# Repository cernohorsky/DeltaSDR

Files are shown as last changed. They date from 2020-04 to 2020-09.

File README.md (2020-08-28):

# DeltaSDR
HF Software Defined Radio Transceiver that includes ADC and DAC circuits. No soundcard is needed. Board communicates only trough one USB cable. Very good software support trough Hamlib. Ideal for digital modes such a FT8 on Raspberry Pi.

- 96kHz digital I/Q interface.
- more then 80dB dynamic range.
- DG8SAQ/PE0FKO/SoftRock control interface.
- Open Source firmware (https://github.com/AE9RB/peaberry)
- SWD/JTAG port.

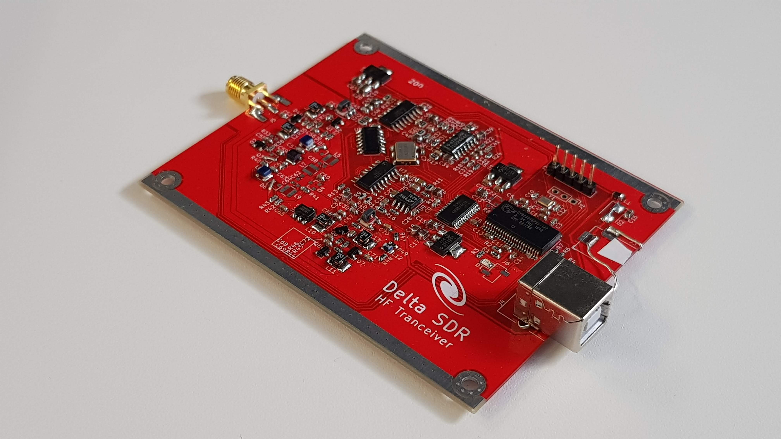
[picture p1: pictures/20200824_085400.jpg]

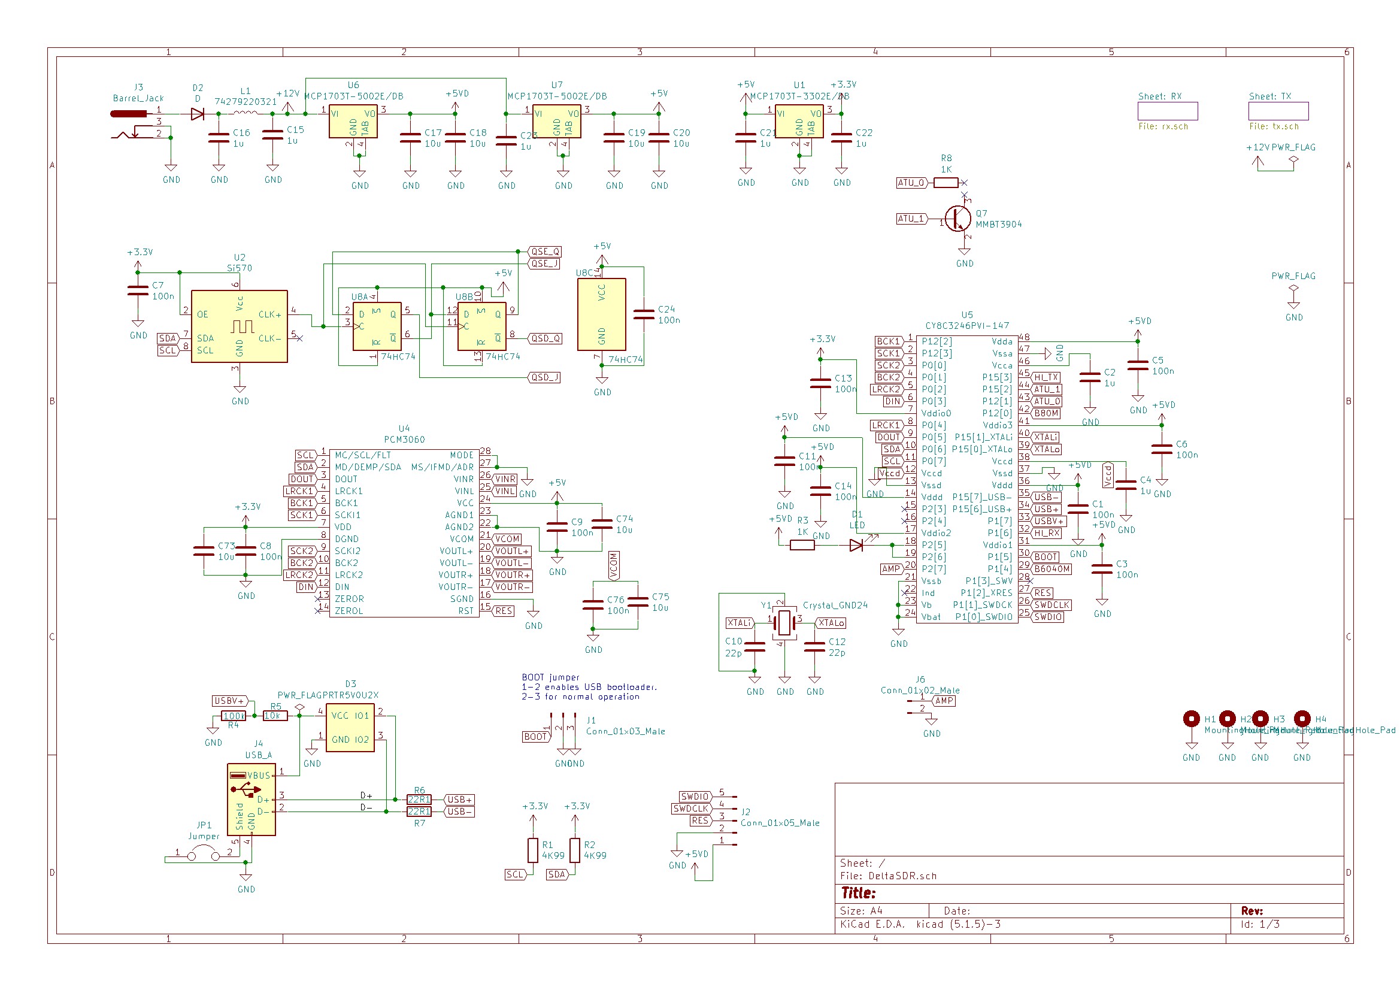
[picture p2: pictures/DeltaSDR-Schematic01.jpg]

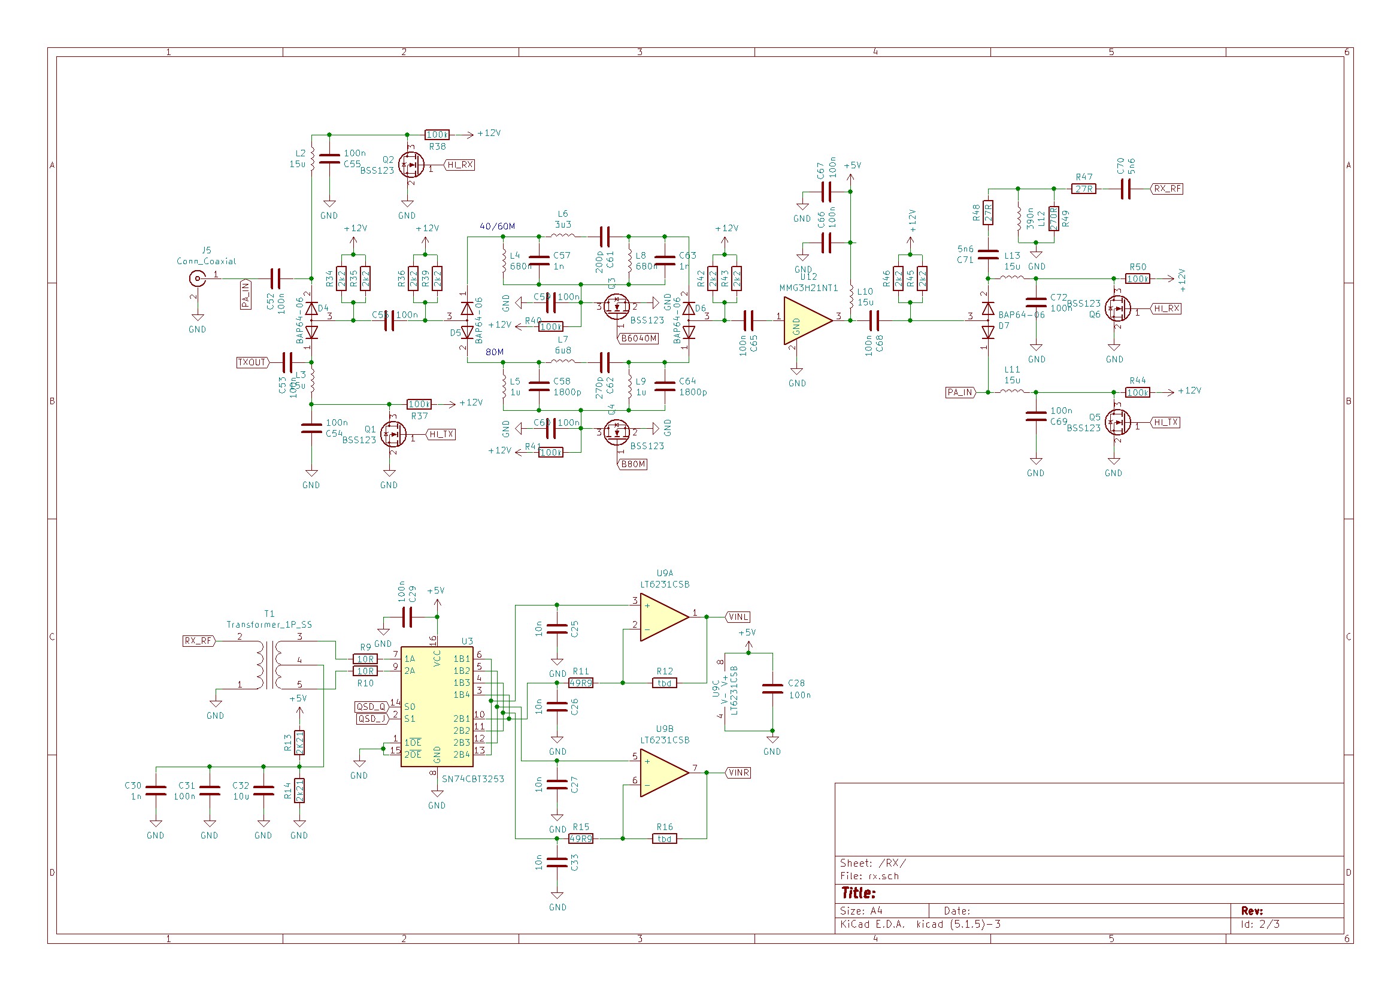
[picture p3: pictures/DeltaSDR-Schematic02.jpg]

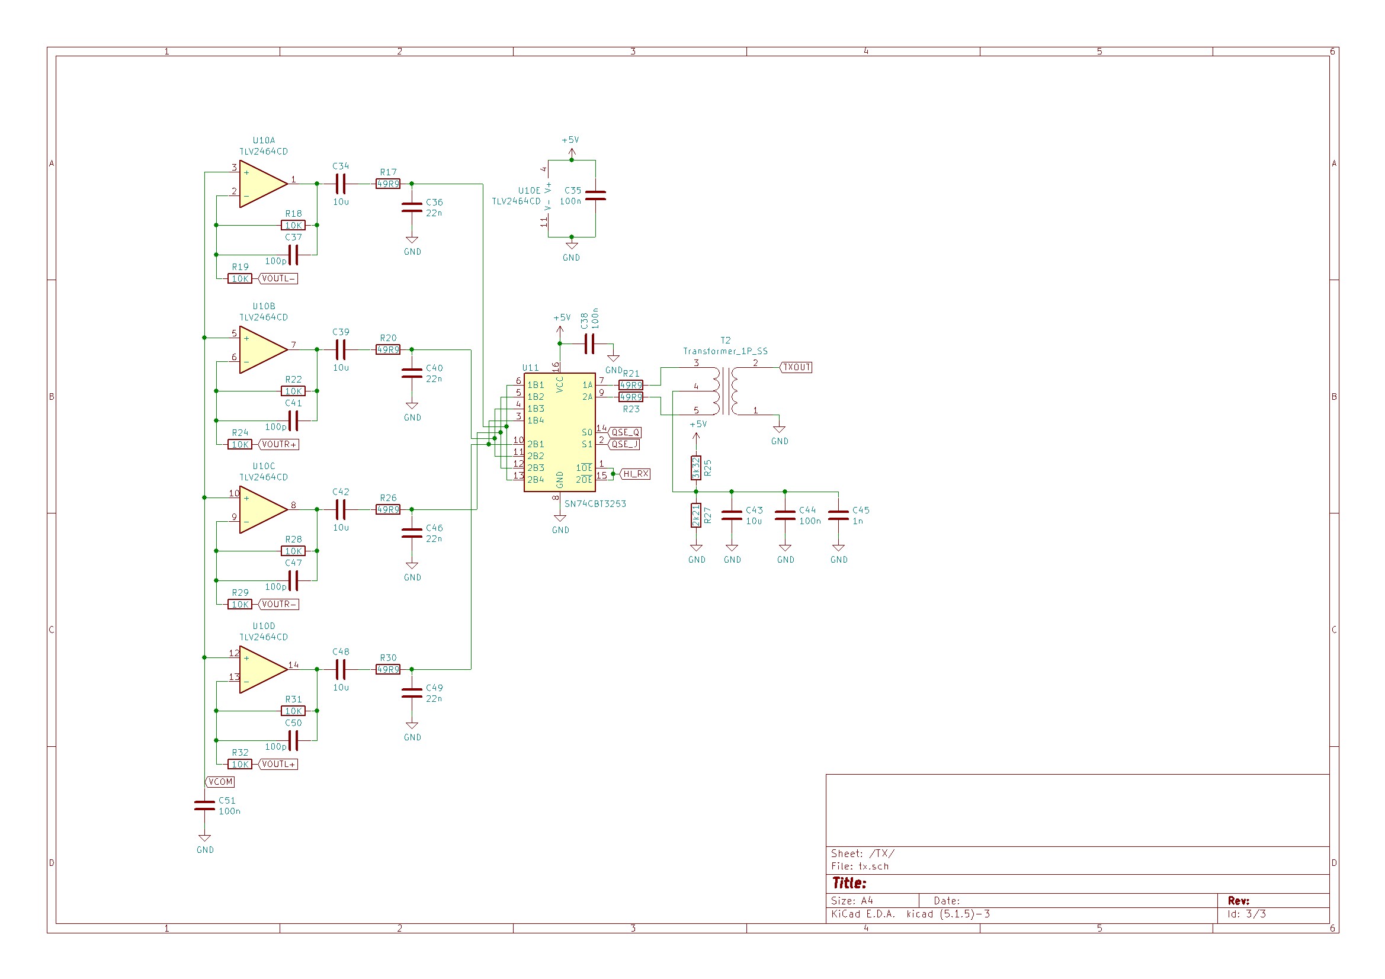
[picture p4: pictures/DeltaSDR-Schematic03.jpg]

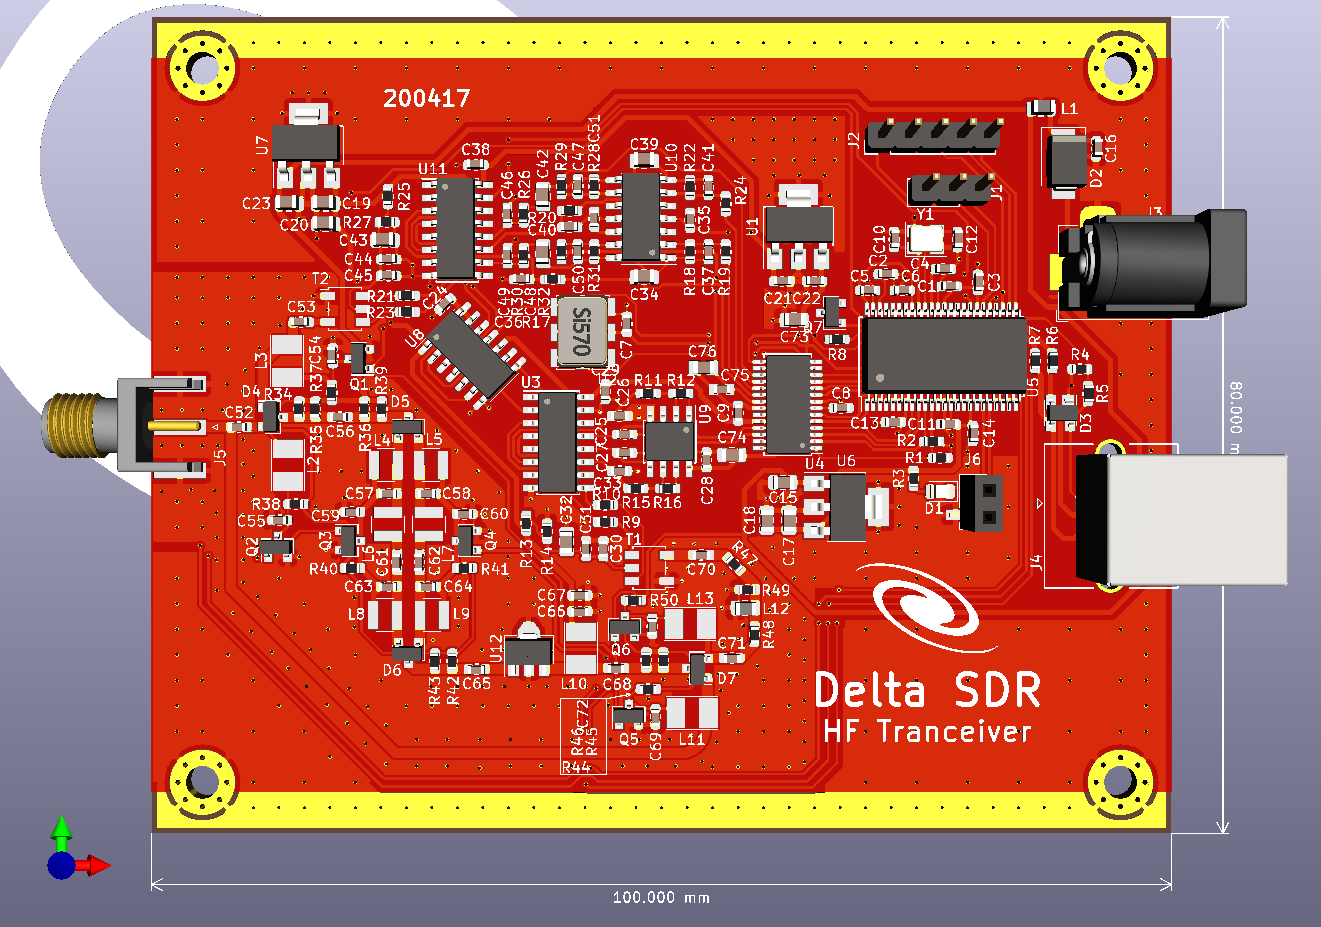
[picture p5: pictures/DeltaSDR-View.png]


ToDo:
- Change SMA and USB footprints
- Add PA
- Implement band switching

Based on: AE9RB Peaberry SDR and RS-HFIQ Transceiver

#sdr, #hf, #ham, #radio, #ft8, #wsjt-x, #shortwave, #usb

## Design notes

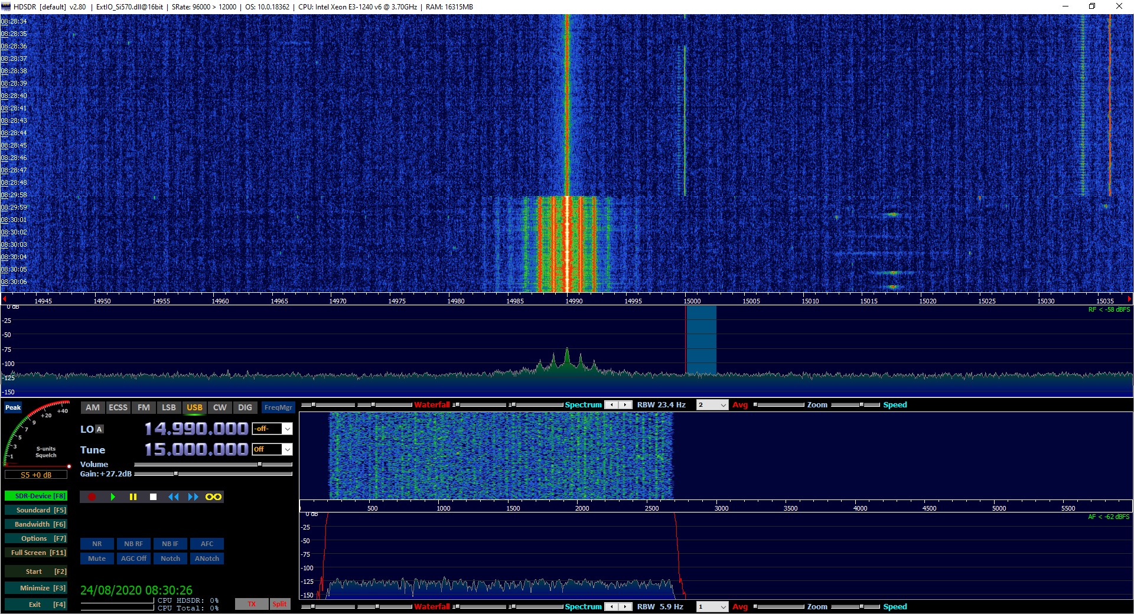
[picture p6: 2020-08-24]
pictures/20200824-DeltaSDR-LinearVsUSB.jpg

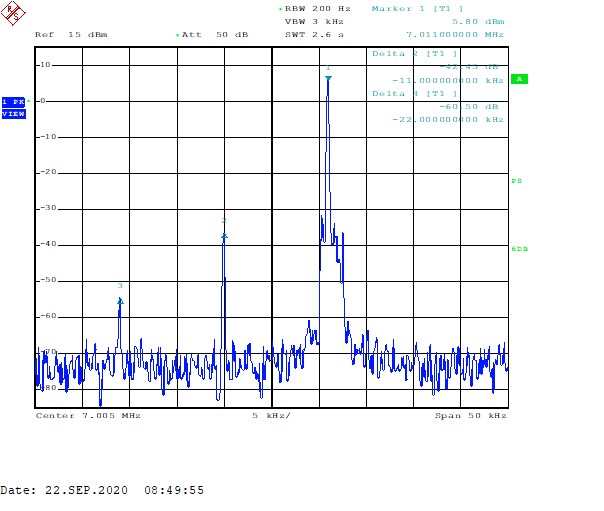
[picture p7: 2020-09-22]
pictures/20200922-DELTA-SDR-TX.jpg

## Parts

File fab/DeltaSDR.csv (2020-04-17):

Id | Designator | Package | Quantity | Designation | Supplier and ref
1 | C74,C73,C39,C32,C43,C48,C42,C34,C23,C20,C19,C18,C17,C15 | C_0805_2012Metric | 14 | 10u
2 | C24,C72,C69,C68,C67,C66,C65,C60,C59,C56,C55,C54,C53,C52,C51,C50,C47,C44,C41,C38,C37,C35,C31,C29,C28,C14,C13,C11,C9,C8,C7,C6,C5,C3,C1 | C_0603_1608Metric | 35 | 100n
3 | U8 | SOIC-14_3.9x8.7mm_P1.27mm | 1 | 74HC74
4 | J6 | PinSocket_1x02_P2.54mm_Vertical_SMD_Pin1Right | 1 | Conn_01x02_Male
5 | G*** | DeltaSymbol | 1 | LOGO
6 | C16,C22,C21,C4,C2 | C_0603_1608Metric | 5 | 1u
7 | L1 | L_0805_2012Metric | 1 | 74279220321
8 | D2 | D_SMB | 1 | D
9 | G*** | RiskeLogo | 1 | RiskeLogo
10 | U1 | SOT-223 | 1 | TC1262-33
11 | U7,U6 | SOT-223 | 2 | TC1262-5
12 | H4,H3,H2,H1 | MountingHole_3.2mm_M3_Pad_Via | 4 | MountingHole_Pad
13 | JP1 | SolderJumper-2_P1.3mm_Open_RoundedPad1.0x1.5mm | 1 | Jumper
14 | R5 | R_0603_1608Metric | 1 | 10k
15 | C70,C71 | C_0603_1608Metric | 2 | 5n6
16 | R13 | R_0603_1608Metric | 1 | 2K21
17 | R14,R27 | R_0603_1608Metric | 2 | 2k21
18 | J3 | BarrelJack_Horizontal | 1 | Barrel_Jack
19 | T2,T1 | Transformer_MACOM_SM-22 | 2 | Transformer_1P_SS
20 | U11,U3 | SOIC-16_4.55x10.3mm_P1.27mm | 2 | SN74CBT3253
21 | Y1 | Crystal_SMD_3225-4Pin_3.2x2.5mm | 1 | Crystal_GND24
22 | U12 | SOT-89-3 | 1 | MMG3H21NT1
23 | U10 | SOIC-14_3.9x8.7mm_P1.27mm | 1 | TLV2464CD
24 | U9 | SO-8_3.9x4.9mm_P1.27mm | 1 | LT6231CSB
25 | U5 | SSOP-48_7.5x15.9mm_P0.635mm | 1 | CY8C3246PVI-147
26 | U4 | TSSOP-28_4.4x9.7mm_P0.65mm | 1 | PCM3060
27 | U2 | Oscillator_SMD_SI570_SI571_Standard | 1 | Si570
28 | R50,R44,R41,R40,R38,R37,R4 | R_0603_1608Metric | 7 | 100k
29 | R49 | R_0603_1608Metric | 1 | 270R
30 | R48,R47 | R_0603_1608Metric | 2 | 27R
31 | R46,R45,R43,R42,R39,R36,R35,R34,R33 | R_0603_1608Metric | 9 | 2k2
32 | R32,R31,R29,R28,R24,R22,R19,R18 | R_0603_1608Metric | 8 | 10K
33 | R30,R26,R23,R21,R20,R17 | R_0603_1608Metric | 6 | 49k9
34 | R25 | R_0603_1608Metric | 1 | 3k32
35 | R16,R12 | R_0603_1608Metric | 2 | tbd
36 | R15,R11 | R_0603_1608Metric | 2 | 49R9
37 | R10,R9 | R_0603_1608Metric | 2 | 10R
38 | R7,R6 | R_0603_1608Metric | 2 | 22R1
39 | R3,R8 | R_0603_1608Metric | 2 | 1K
40 | R2,R1 | R_0603_1608Metric | 2 | 4K99
41 | Q6,Q5,Q4,Q3,Q2,Q1 | SOT-23 | 6 | BSS123
42 | L13,L11,L10,L3,L2 | L_Taiyo-Yuden_NR-30xx_HandSoldering | 5 | 15u
43 | L12 | L_0805_2012Metric | 1 | 390n
44 | L9,L5 | L_Abracon_ASPI-3012S | 2 | 1u
45 | L8,L4 | L_Abracon_ASPI-3012S | 2 | 680n
46 | L7 | L_Abracon_ASPI-3012S | 1 | 6u8
47 | L6 | L_Abracon_ASPI-3012S | 1 | 3u3
48 | J5 | SMA_Amphenol_132289_EdgeMount | 1 | Conn_Coaxial
49 | J4 | USB_B_TE_5787834_Vertical | 1 | USB_A
50 | J2 | PinHeader_1x05_P2.54mm_Vertical | 1 | Conn_01x05_Male
51 | J1 | PinHeader_1x03_P2.54mm_Vertical | 1 | Conn_01x03_Male
52 | D7,D6,D5,D4 | SOT-23 | 4 | BAP64-06
53 | D3 | SOT-143 | 1 | PRTR5V0U2X
54 | D1 | LED_0805_2012Metric | 1 | LED
55 | C64,C58 | C_0603_1608Metric | 2 | 1800p
56 | C63,C57,C45,C30 | C_0603_1608Metric | 4 | 1n
57 | C62 | C_0603_1608Metric | 1 | 270p
58 | C61 | C_0603_1608Metric | 1 | 200p
59 | C49,C46,C40,C36 | C_0603_1608Metric | 4 | 22n
60 | C33,C27,C26,C25 | C_0805_2012Metric | 4 | 10n
61 | C12,C10 | C_0603_1608Metric | 2 | 22p
62 | Q7 | SOT-23 | 1 | MMBT3904

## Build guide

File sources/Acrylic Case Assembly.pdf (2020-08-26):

Take some time to study
this first picture. The pieces are laid out how they will fit together. The top piece is not in the photograph.

All pieces will have a
protective film on them. Use your fingernail to lift a
corner and it will peel off easily.

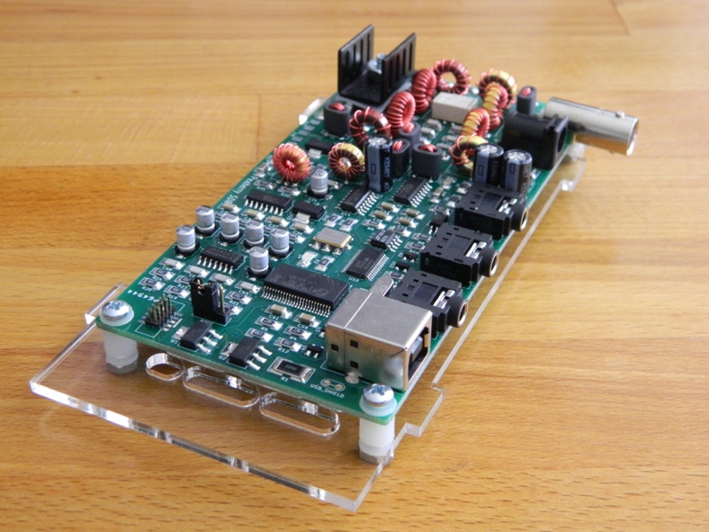
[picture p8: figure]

Begin by attaching the
circuit board to the bottom panel. The 1/2” #4 screws
that came with your radio
aren’t long enough so use
the 5/8” #4 screws that
came with the case. The
case also comes with four
more nylon washers to put
between the nut and the
acrylic.

Do not tighten the nuts yet. Allow the board to float
around for now.

Ensure the cooling vents
are positioned as in the
photograph.

# Acrylic Case for Peaberry SDR Page 1/3

Attach the connector panel next. With this in place you can tighten the nuts holding the circuit board.

Expect some resistance the first time you insert a tab into a slot.

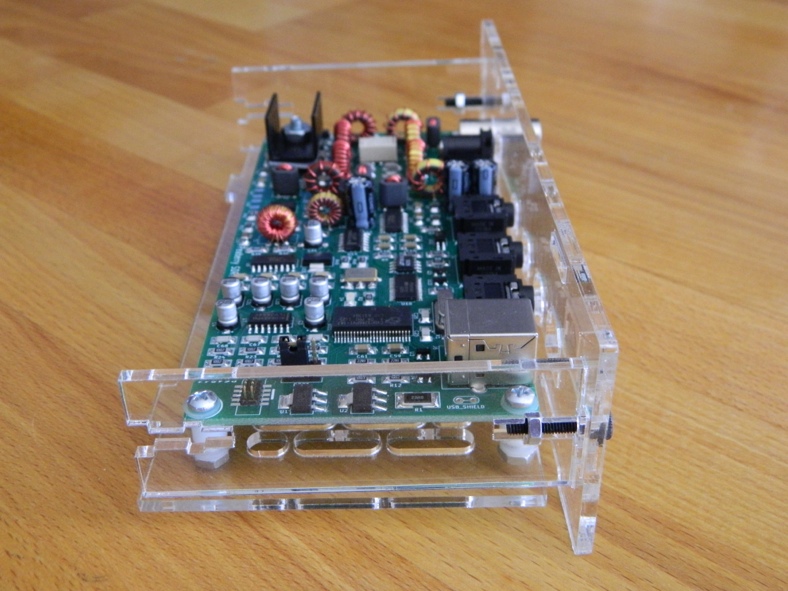
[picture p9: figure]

Install the inner side panels and the M3 hardware. Hold
the nuts in place with your fingers when starting the
screw. Install the screws
only finger-tight for now.

Install the next panel and M3 hardware. Once in
place you will have to
loosen the M3 hardware
and install the remaining
three panels. This
procedure is a little wonky but you’ll get through it with a bit of trial and error.

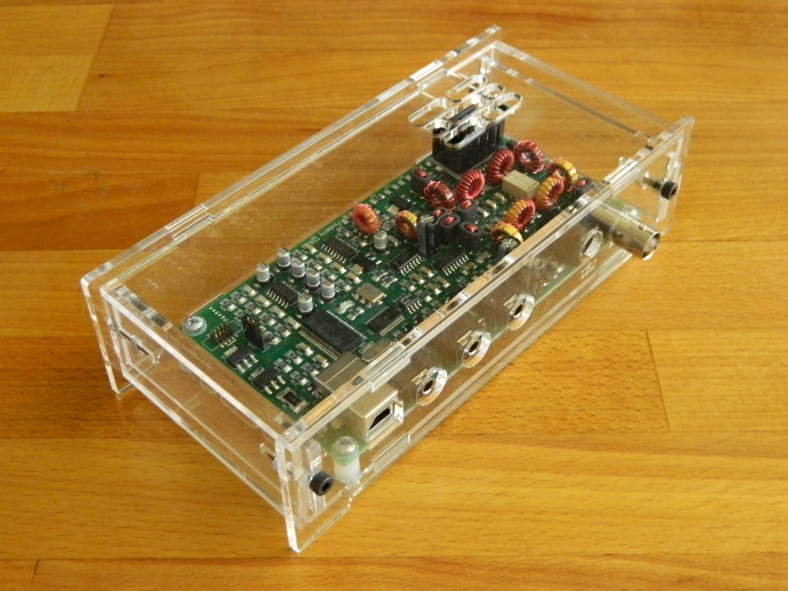
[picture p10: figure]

With all the panels installed you can tighten the M3
hardware with the included wrench. Insert the long end of the wench into the screw caps so you do not overtighten these.

Enjoy your new case. Clean with a damp cloth using
regular soap if needed. Do not use any ammoniabased cleaners.

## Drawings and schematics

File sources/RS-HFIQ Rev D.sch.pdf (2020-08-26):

A

A

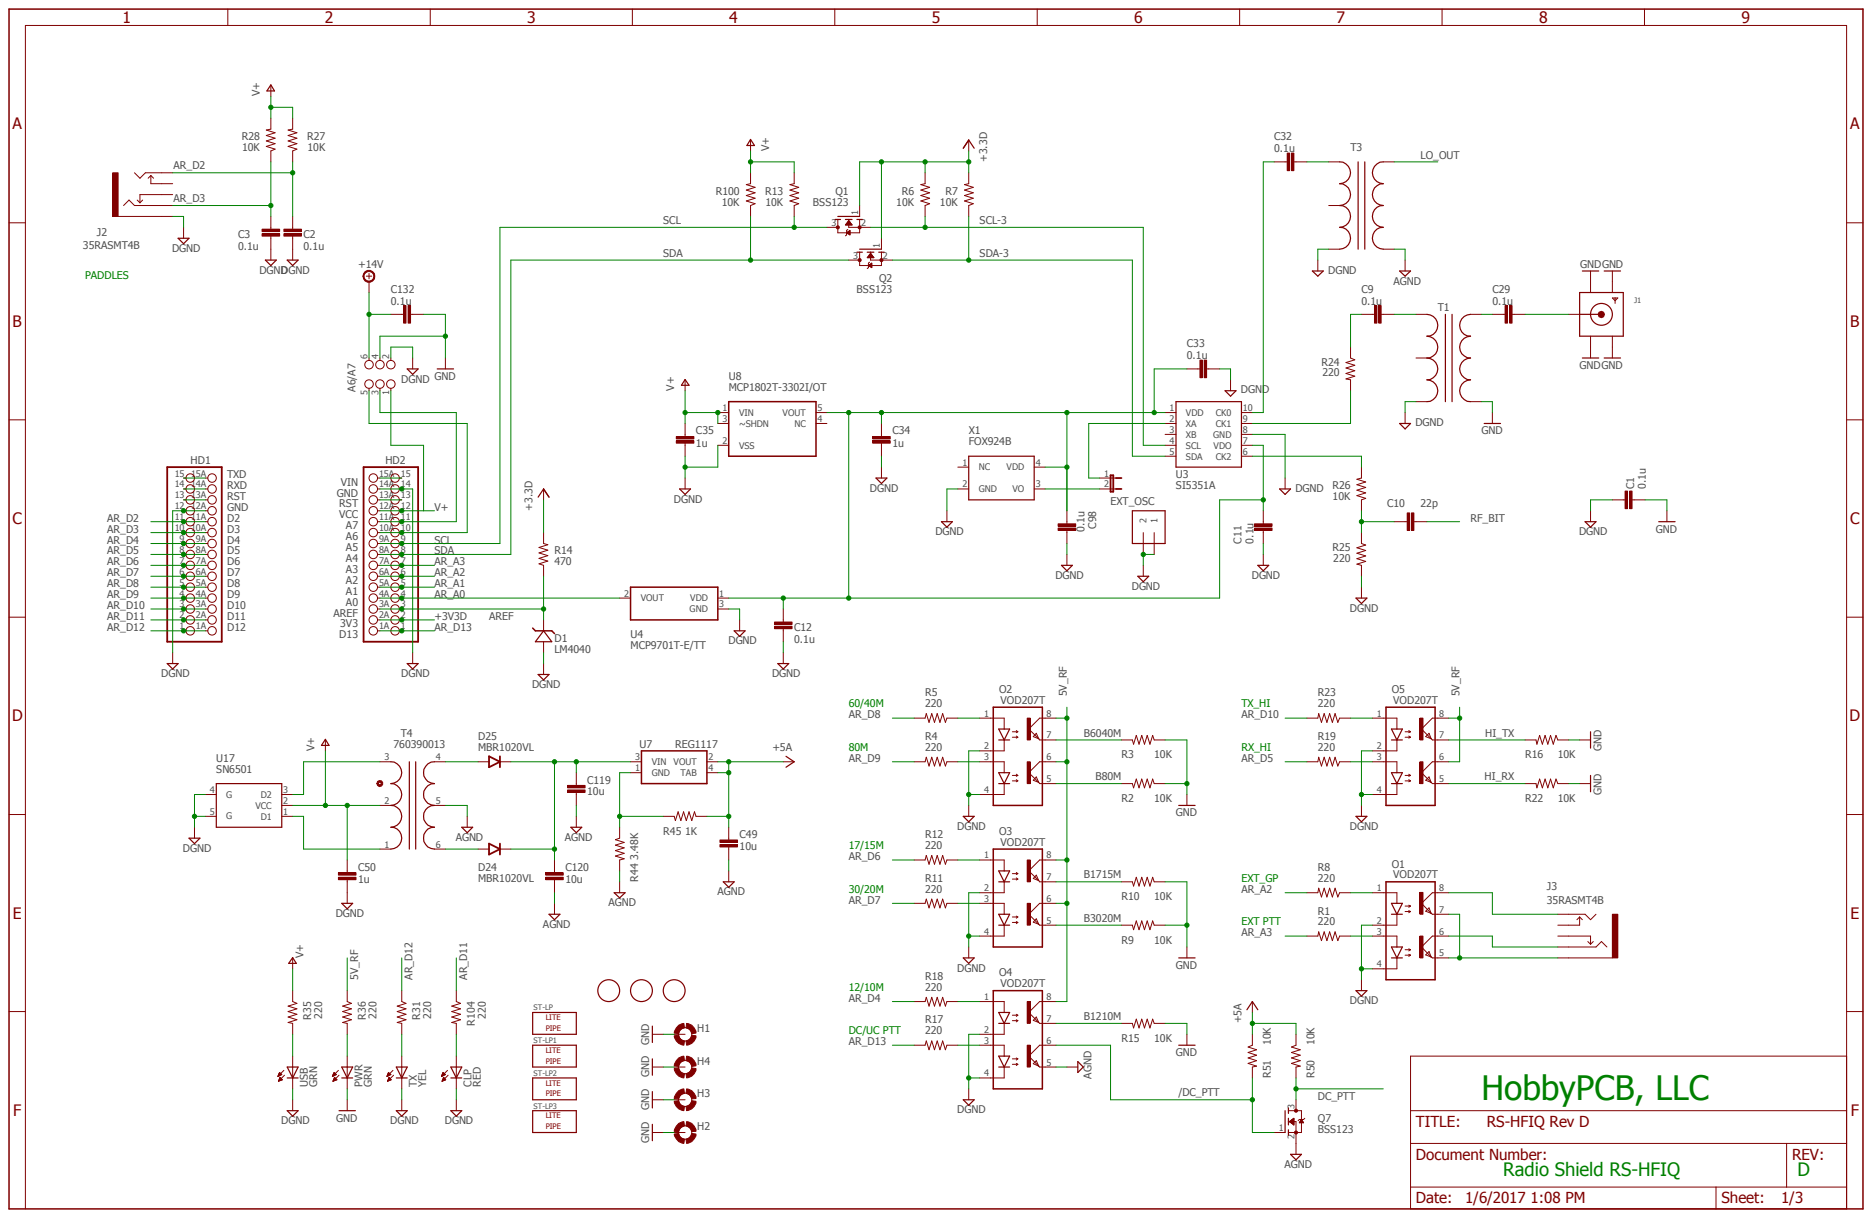
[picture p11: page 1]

GND GND

Document Number: Radio Shield RS-HFIQ | REV: D

Date: 1/6/2017 1:08 PM | Sheet: 1/3

A

A

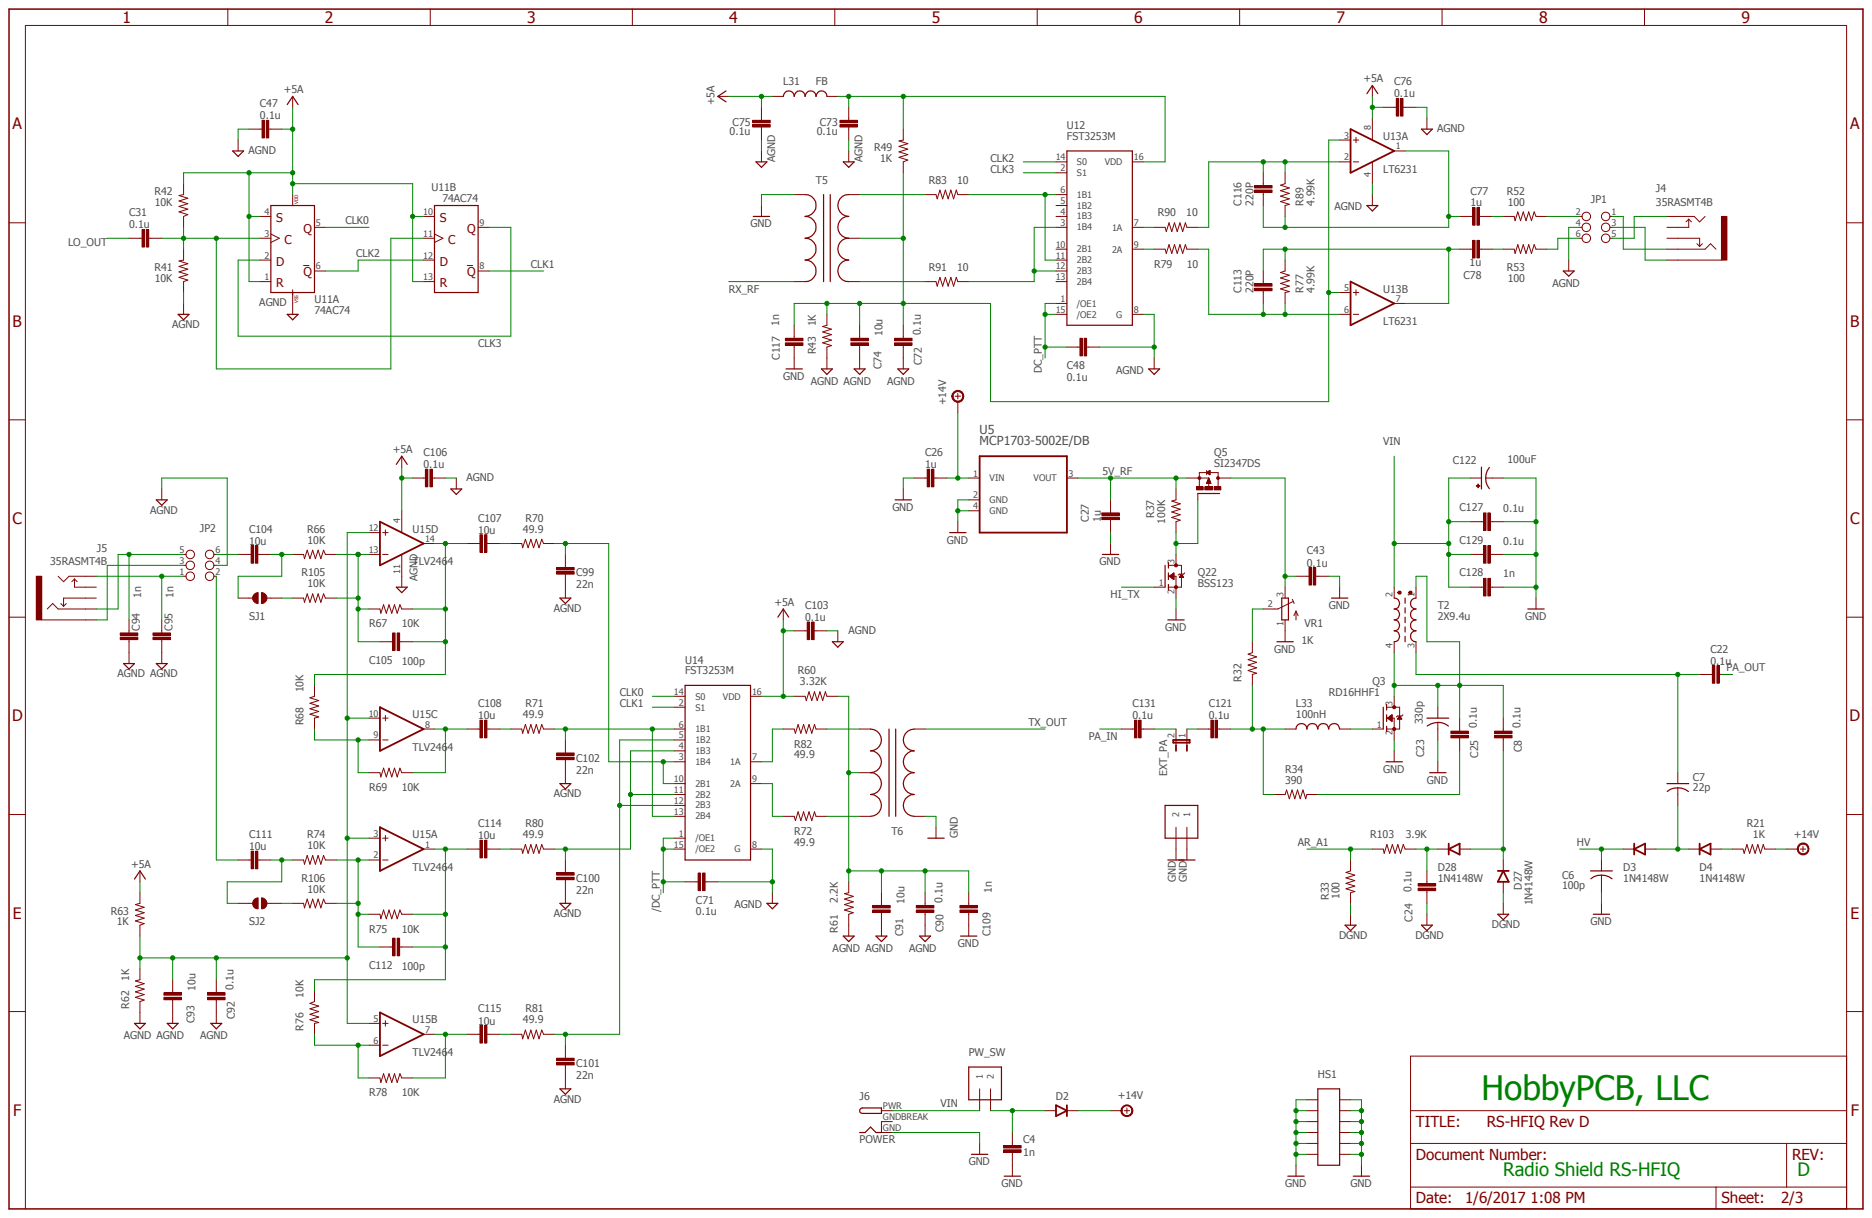
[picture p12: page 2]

Document Number: Radio Shield RS-HFIQ | REV: D

Date: 1/6/2017 1:08 PM | Sheet: 2/3

J7
A

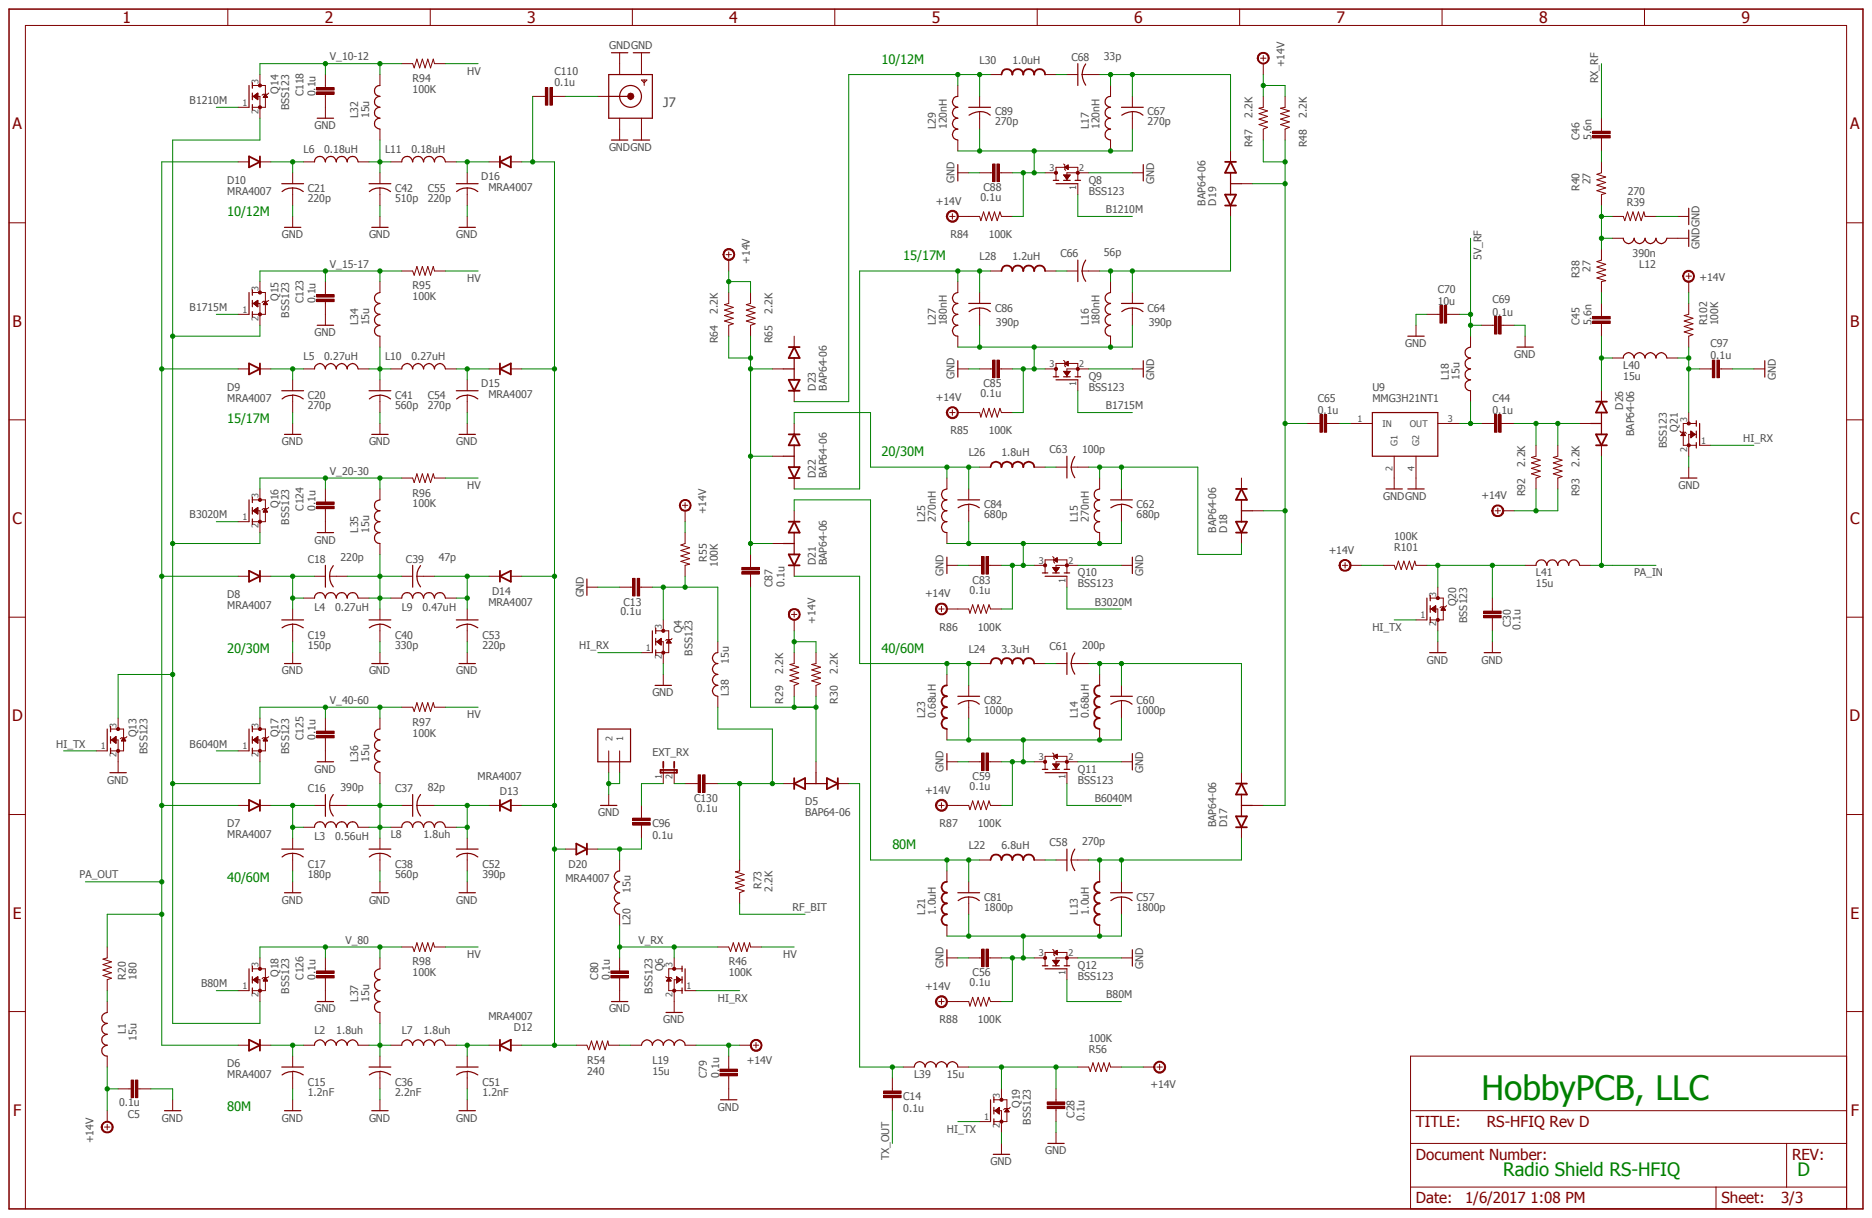
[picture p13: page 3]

Document Number: Radio Shield RS-HFIQ | REV: D

Date: 1/6/2017 1:08 PM | Sheet: 3/3

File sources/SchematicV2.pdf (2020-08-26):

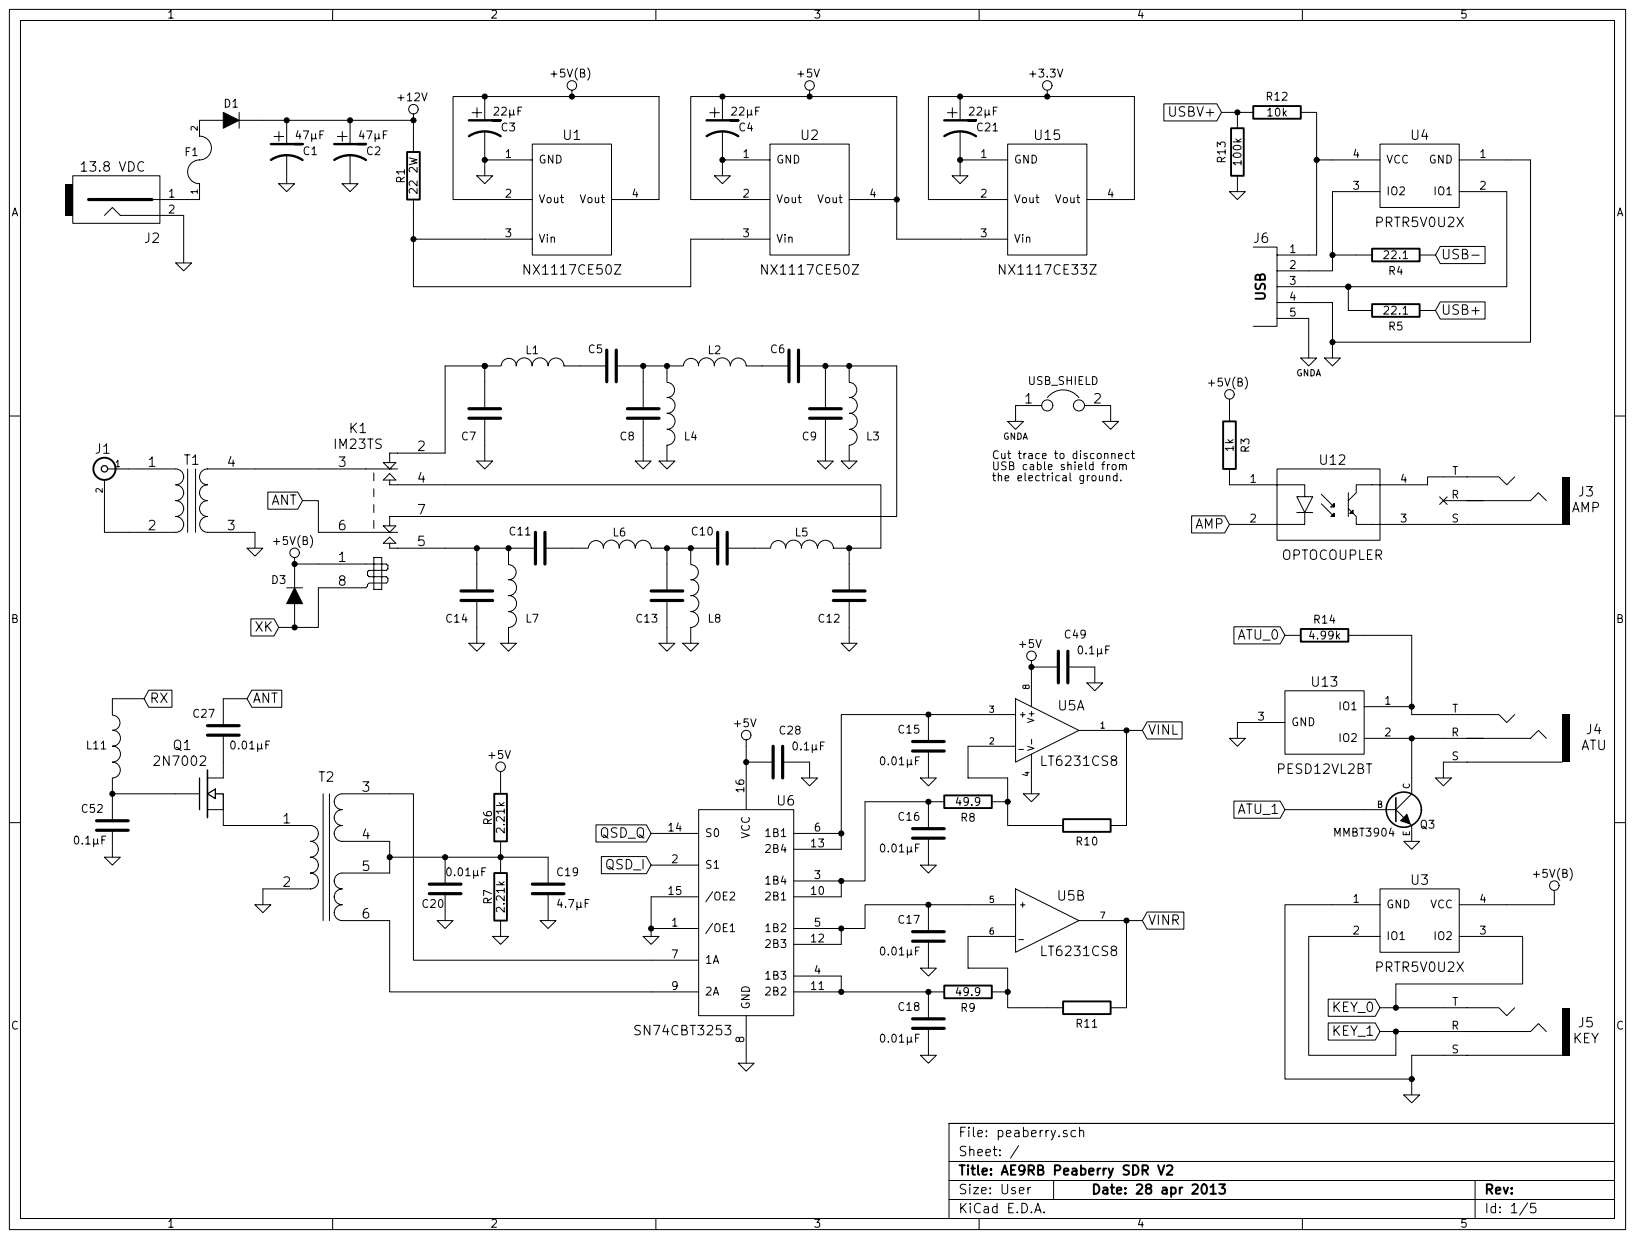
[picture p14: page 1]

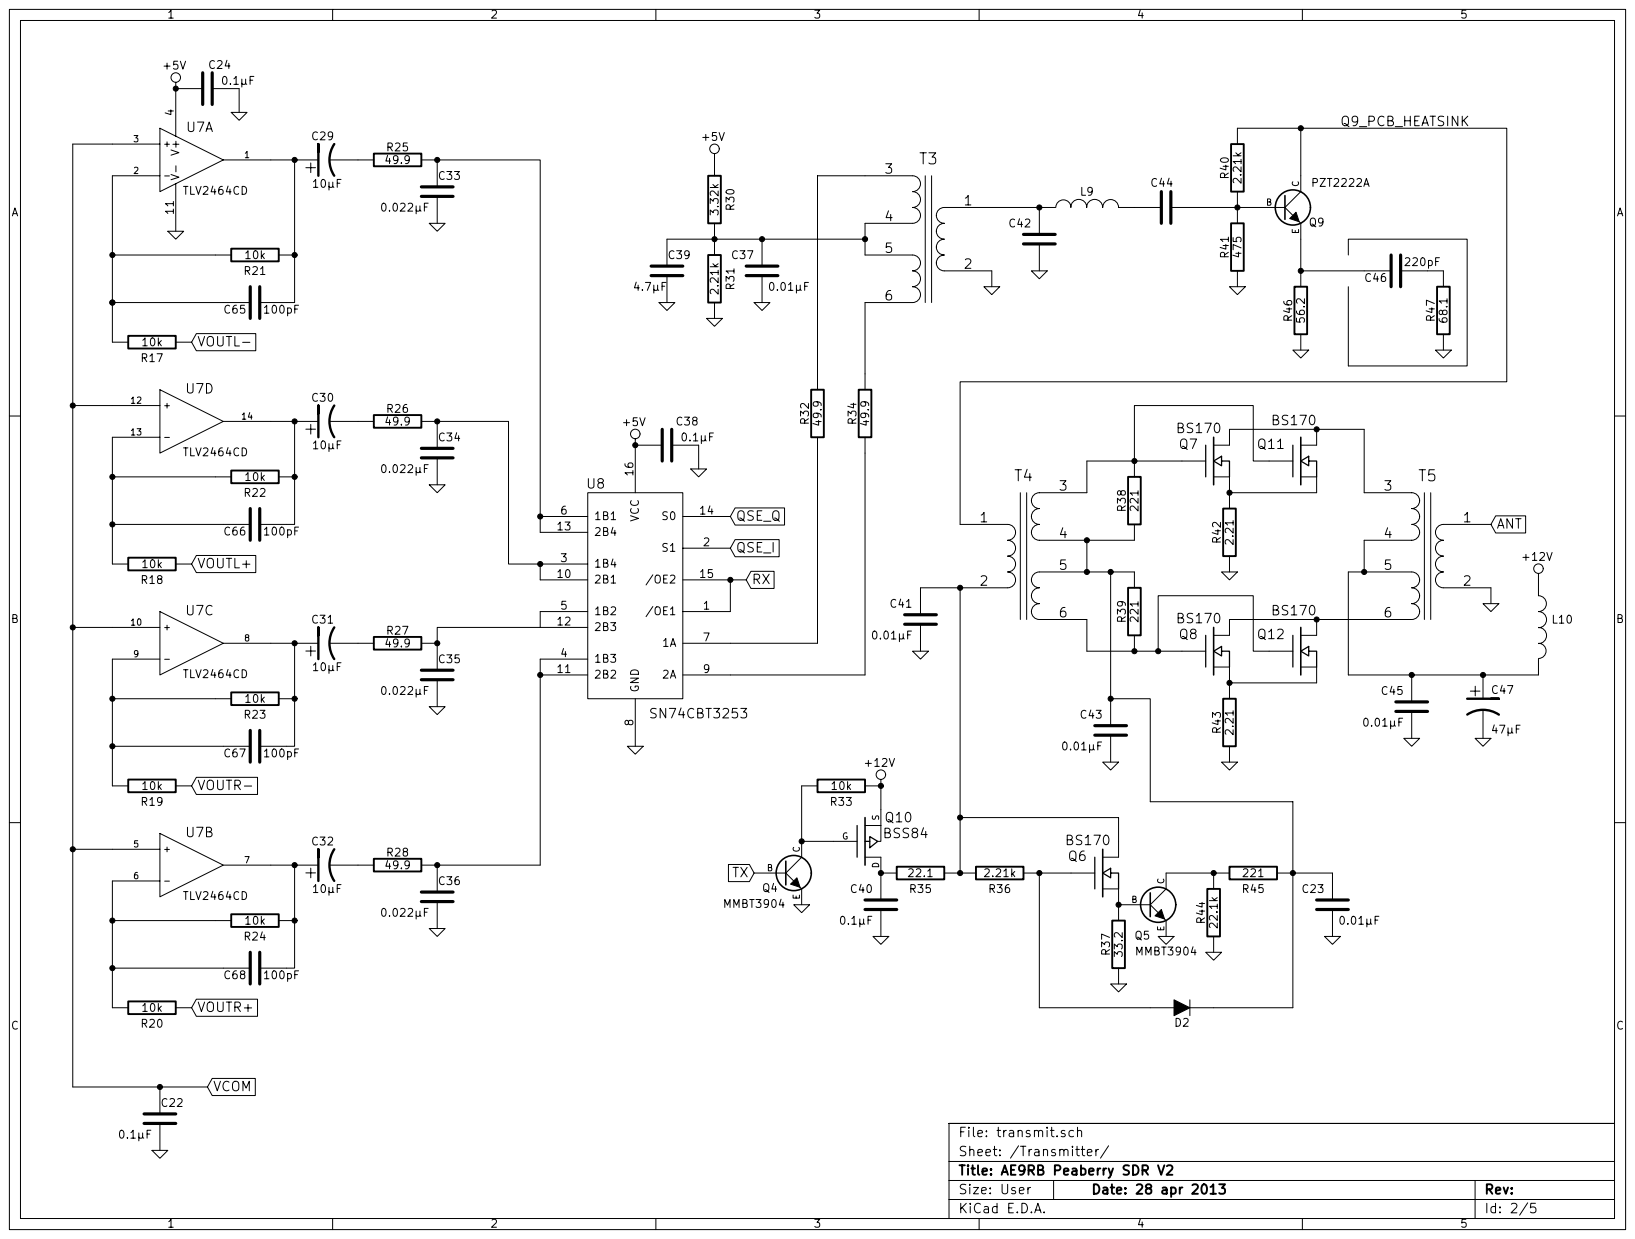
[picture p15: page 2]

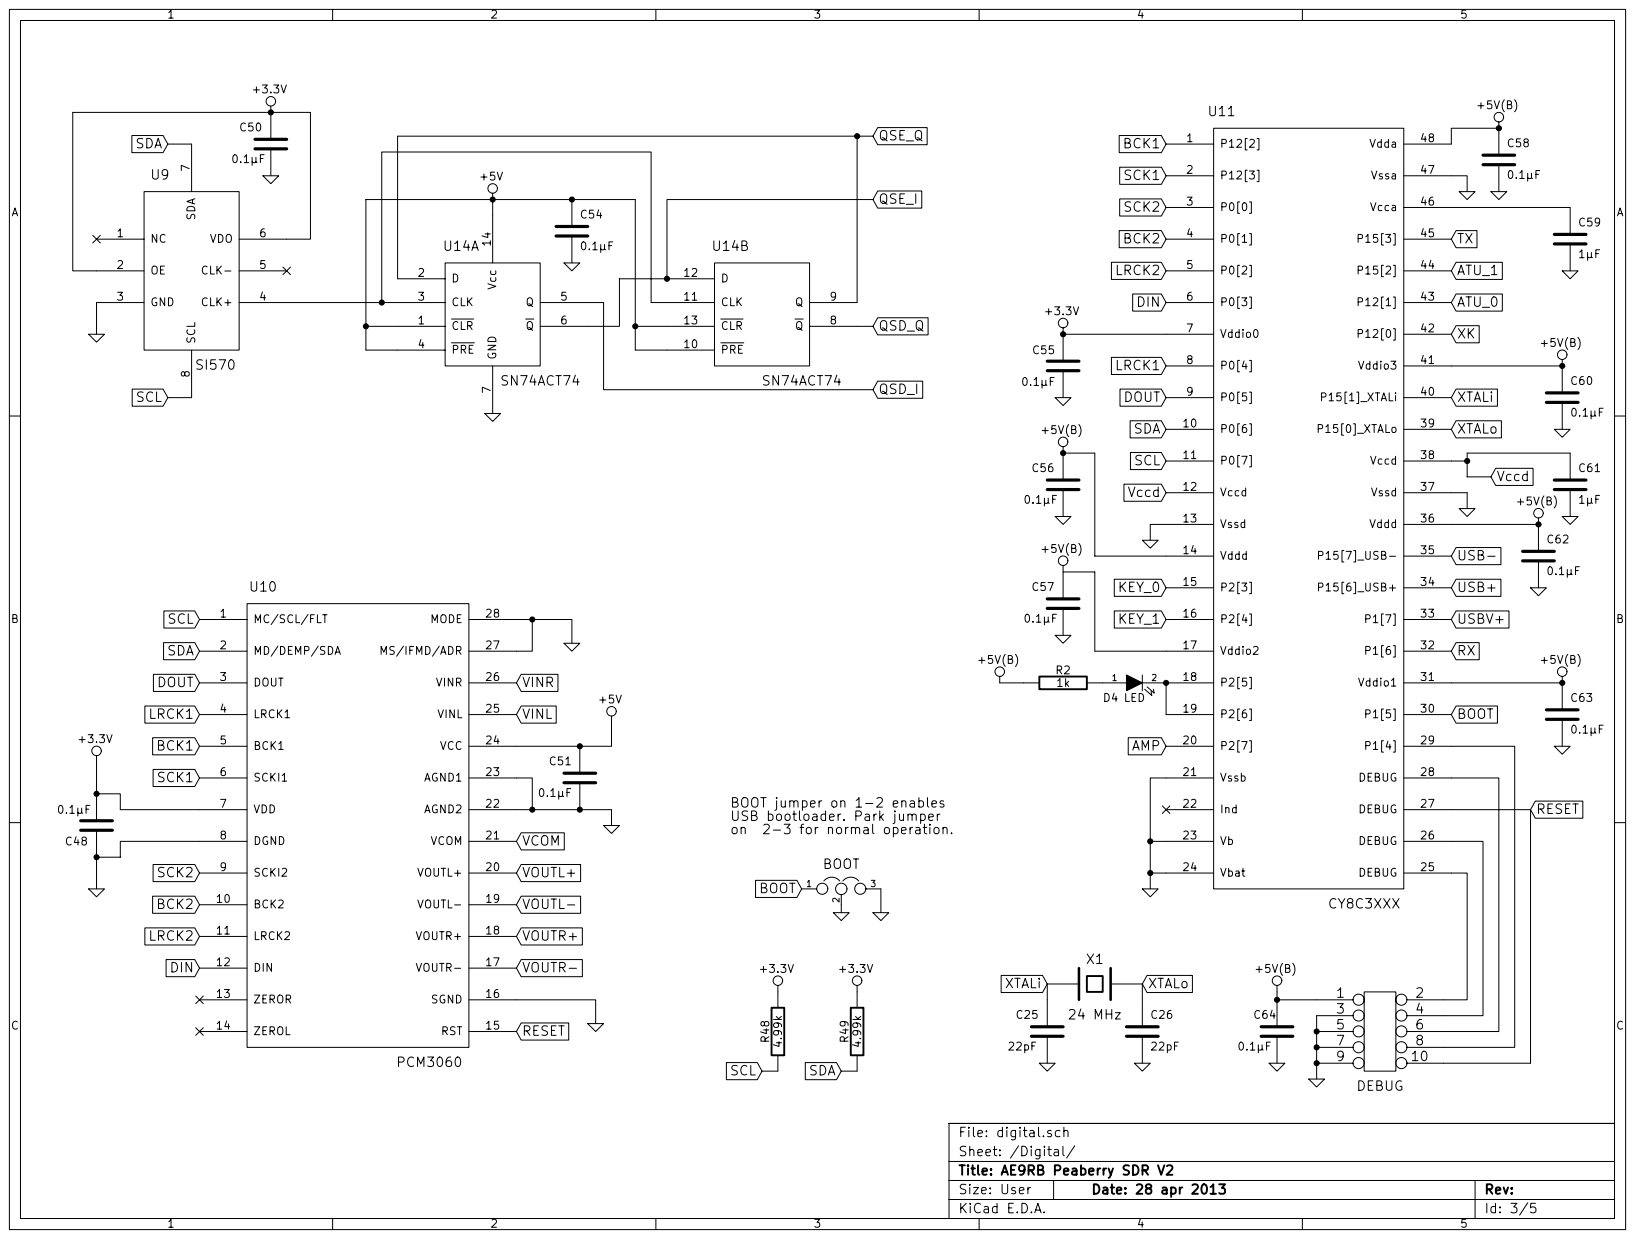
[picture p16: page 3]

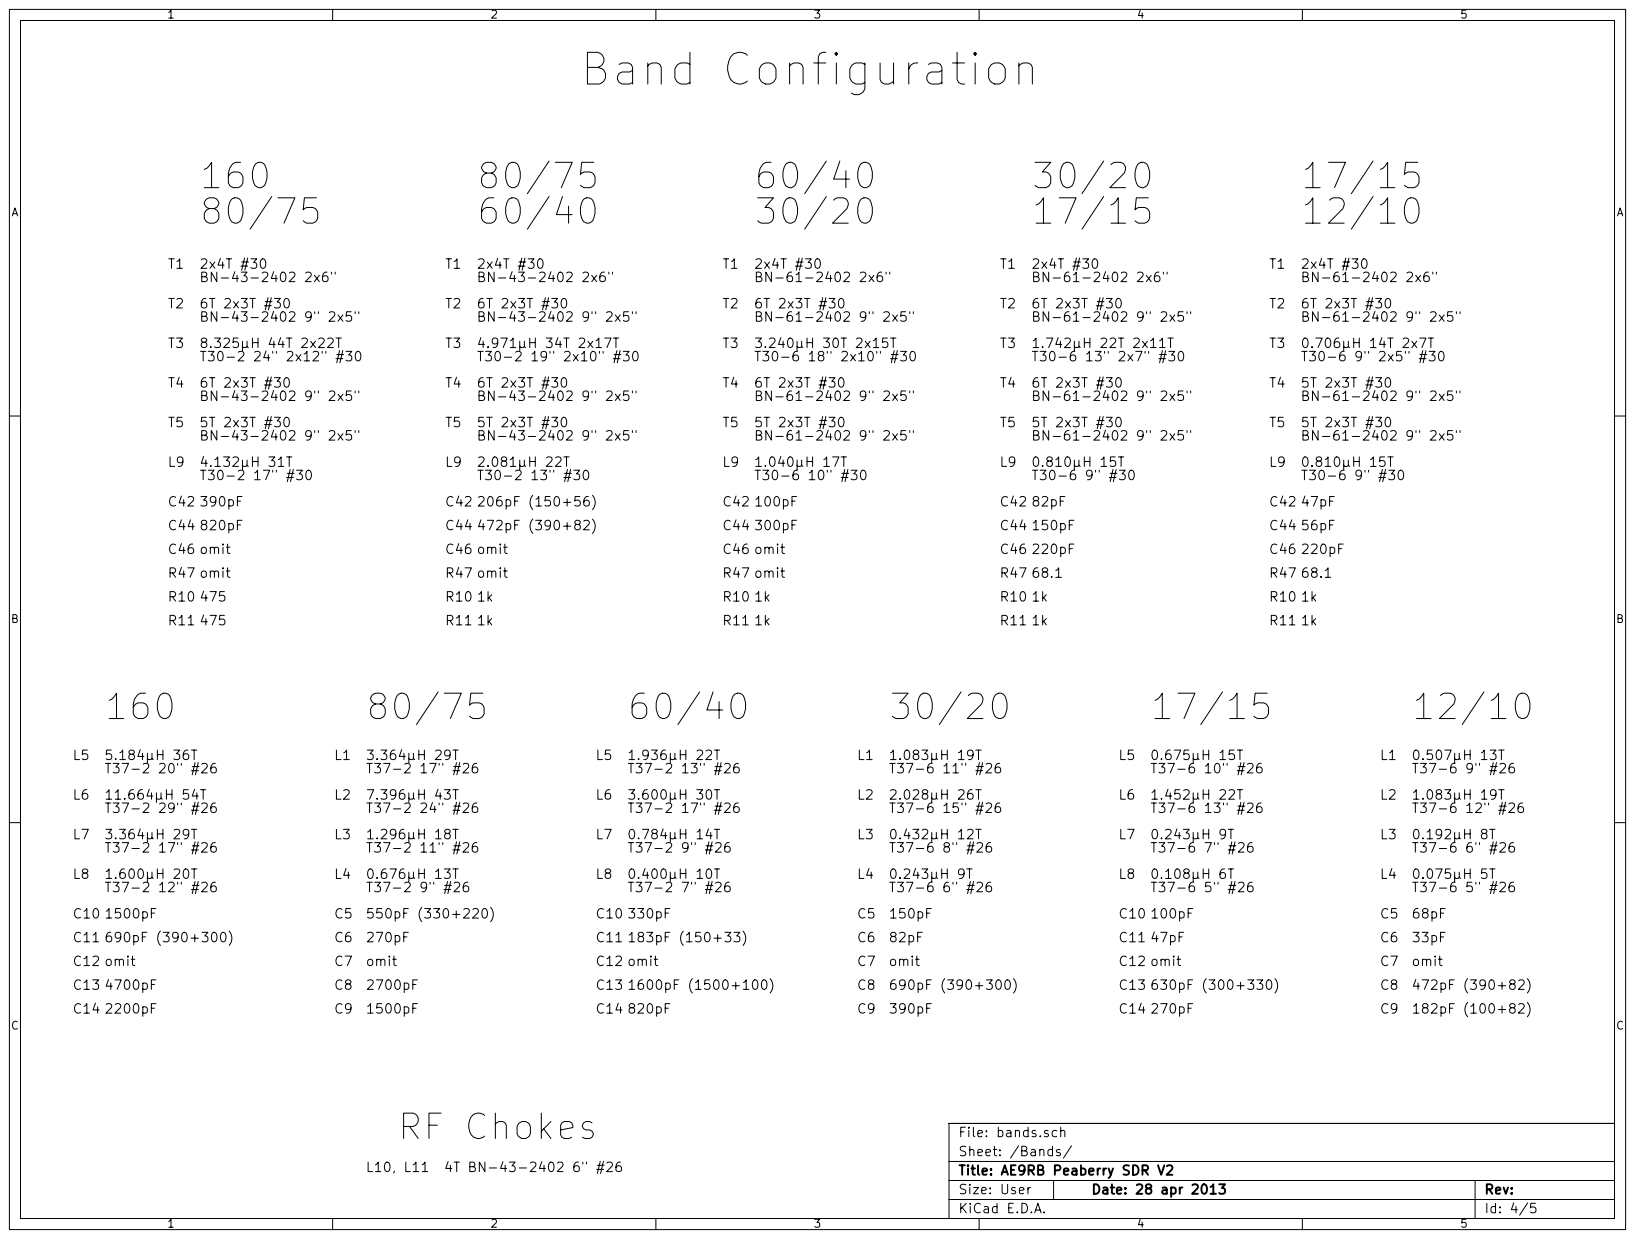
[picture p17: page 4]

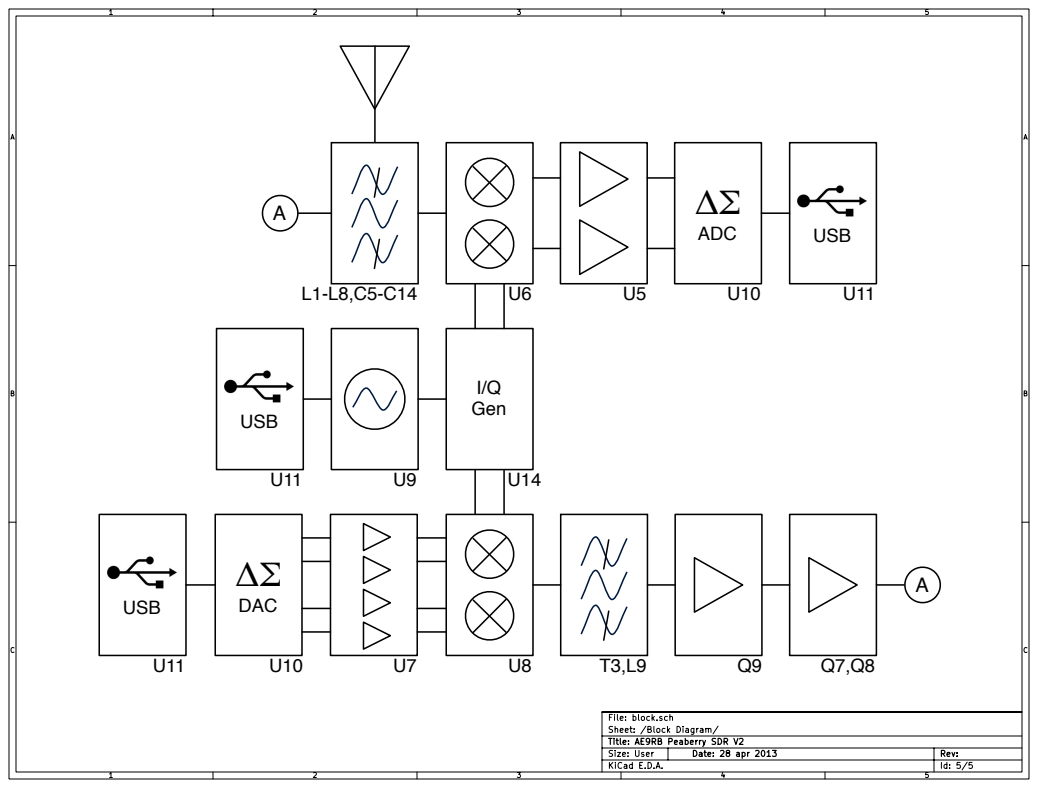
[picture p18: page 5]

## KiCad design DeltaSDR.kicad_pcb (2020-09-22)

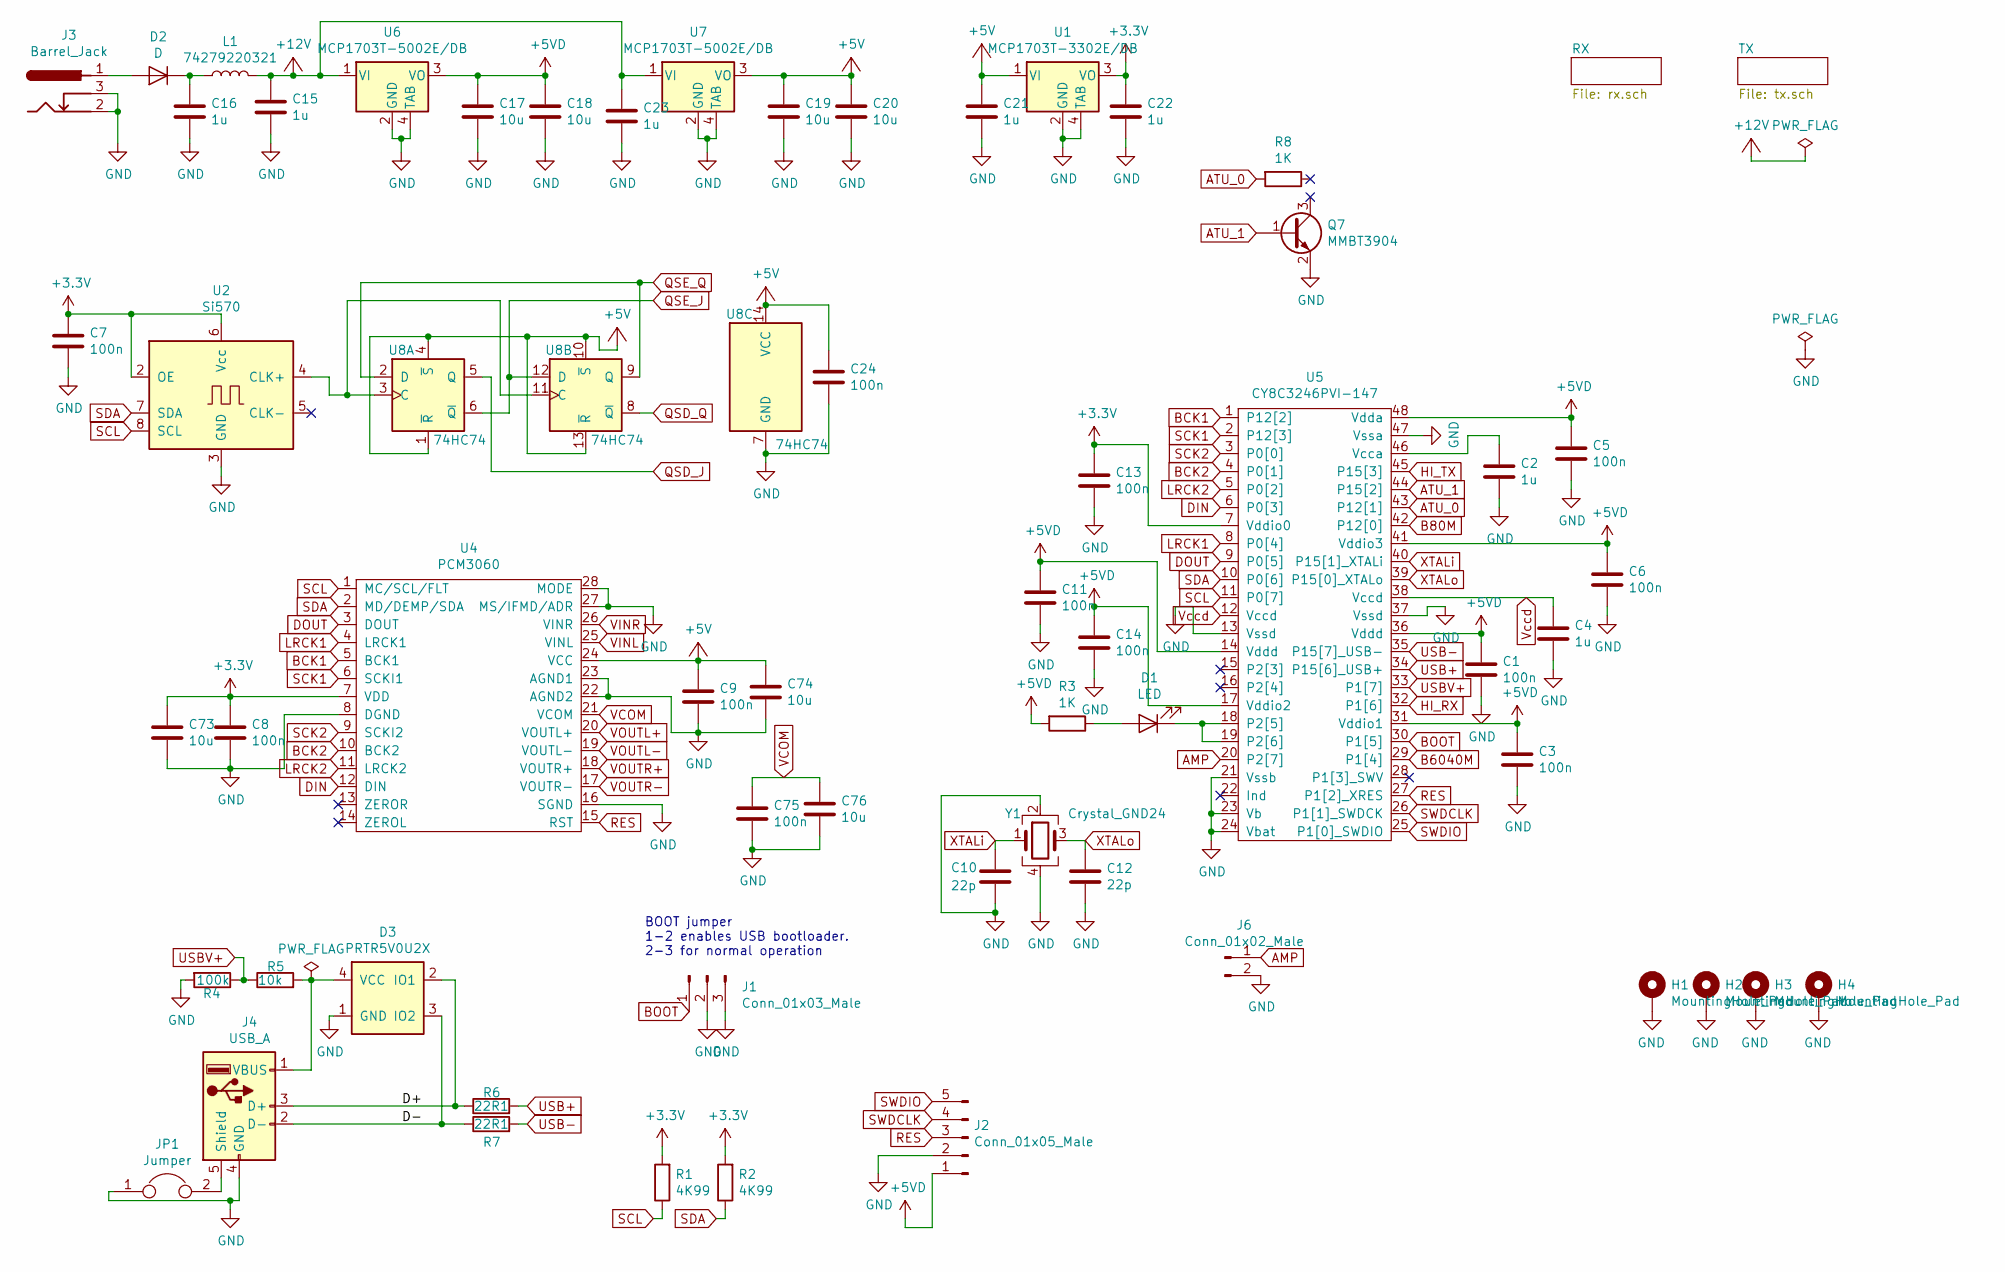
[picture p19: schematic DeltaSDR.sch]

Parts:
C1, C3, C5, C6, C7, C8, C9, C11, C13, C14, C24, C75: 100n; C_0603_1608Metric
C2, C4, C16, C21, C22: 1u; C_0603_1608Metric
C10, C12: 22p; C_0603_1608Metric
C15, C23: 1u; C_0805_2012Metric
C17, C18, C19, C20, C73, C74, C76: 10u; C_0805_2012Metric
D1: LED; LED_0805_2012Metric
D2: D; D_SMB
D3: PRTR5V0U2X; SOT-143
H1, H2, H3, H4: MountingHole_Pad; MountingHole_3.2mm_M3_Pad_Via
J1: Conn_01x03_Male; PinHeader_1x03_P2.54mm_Vertical
J2: Conn_01x05_Male; PinHeader_1x05_P2.54mm_Vertical
J3: Barrel_Jack; BarrelJack_Horizontal
J4: USB_A; USB_B_TE_5787834_Vertical
J6: Conn_01x02_Male; PinSocket_1x02_P2.54mm_Vertical_SMD_Pin1Right
JP1: Jumper; SolderJumper-2_P1.3mm_Open_RoundedPad1.0x1.5mm
L1: 74279220321; L_0805_2012Metric
Q7: MMBT3904; SOT-23
R1, R2: 4K99; R_0603_1608Metric
R3, R8: 1K; R_0603_1608Metric
R4: 100k; R_0603_1608Metric
R5: 10k; R_0603_1608Metric
R6, R7: 22R1; R_0603_1608Metric
U1: MCP1703T-3302E/DB; SOT-223
U2: Si570; Oscillator_SMD_SI570_SI571_Standard
U4: PCM3060; TSSOP-28_4.4x9.7mm_P0.65mm
U5: CY8C3246PVI-147; SSOP-48_7.5x15.9mm_P0.635mm
U6, U7: MCP1703T-5002E/DB; SOT-223
U8: 74HC74; SOIC-14_3.9x8.7mm_P1.27mm
Y1: Crystal_GND24; Crystal_SMD_3225-4Pin_3.2x2.5mm

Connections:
+3V3: C7.1, C8.1, C13.1, C22.1, C73.1, R1.2, R2.2, U1.3 (VO), U2.2 (OE), U2.6 (Vcc), U4.7 (VDD), U5.7 (Vddio0)
+5V: C9.1, C19.1, C20.1, C21.1, C24.1, C74.1, U1.1 (VI), U4.24 (VCC), U7.3 (VO), U8.1 (~R), U8.4 (~S), U8.10 (~S), U8.13 (~R), U8.14 (VCC); also elsewhere on the board
+5VD: C1.1, C3.1, C5.1, C6.1, C11.1, C14.1, C17.1, C18.1, J2.1, R3.2, U5.14 (Vddd), U5.17 (Vddio2), U5.31 (Vddio1), U5.36 (Vddd), U5.41 (Vddio3), U5.48 (Vdda), U6.3 (VO)
+12V: C15.1, C23.1, L1.2, U6.1 (VI), U7.1 (VI); also elsewhere on the board
/D+: D3.2 (IO1), J4.3 (D+), R6.1
/D-: D3.3 (IO2), J4.2 (D-), R7.1
AMP: J6.1, U5.20 (P2[7])
ATU_0: R8.2, U5.43 (P12[1])
ATU_1: Q7.1 (B), U5.44 (P15[2])
B80M: U5.42 (P12[0]); also elsewhere on the board
B6040M: U5.29 (P1[4]); also elsewhere on the board
BCK1: U4.5 (BCK1), U5.1 (P12[2])
BCK2: U4.10 (BCK2), U5.4 (P0[1])
BOOT: J1.1, U5.30 (P1[5])
DIN: U4.12 (DIN), U5.6 (P0[3])
DOUT: U4.3 (DOUT), U5.9 (P0[5])
GND: C1.2, C2.2, C3.2, C4.2, C5.2, C6.2, C7.2, C8.2, C9.2, C10.2, C11.2, C12.2, C13.2, C14.2, C15.2, C16.2, C17.2, C18.2, C19.2, C20.2, C21.2, C22.2, C23.2, C24.2, C73.2, C74.2, C75.2, C76.2, D3.1 (GND), H1.1, H2.1, H3.1, H4.1, J1.2, J1.3, J2.2, J3.2, J3.3, J4.4 (GND), J6.2, JP1.1, Q7.2 (E), R4.2, U1.2 (GND), U1.4 (TAB), U2.3 (GND), U4.8 (DGND), U4.16 (SGND), U4.22 (AGND2), U4.23 (AGND1), U4.27 (MS/IFMD/ADR), U4.28 (MODE), U5.13 (Vssd), U5.21 (Vssb), U5.23 (Vb), U5.24 (Vbat), U5.37 (Vssd), U5.47 (Vssa), U6.2 (GND), U6.4 (TAB), U7.2 (GND), U7.4 (TAB), U8.7 (GND), Y1.2, Y1.4; also elsewhere on the board
HI_RX: U5.32 (P1[6]); also elsewhere on the board
HI_TX: U5.45 (P15[3]); also elsewhere on the board
LRCK1: U4.4 (LRCK1), U5.8 (P0[4])
LRCK2: U4.11 (LRCK2), U5.5 (P0[2])
unnamed: C2.1, U5.46 (Vcca)
unnamed: C16.1, D2.1 (K), L1.1
unnamed: D1.1 (K), U5.18 (P2[5]), U5.19 (P2[6])
unnamed: D1.2 (A), R3.1
unnamed: D2.2 (A), J3.1
unnamed: D3.4 (VCC), J4.1 (VBUS), R5.2
unnamed: J4.5 (Shield), JP1.2
unnamed: U2.4 (CLK+), U8.3 (C), U8.11 (C)
QSD_J: U8.5 (Q); also elsewhere on the board
QSD_Q: U8.8 (~Q); also elsewhere on the board
QSE_J: U8.6 (~Q), U8.12 (D); also elsewhere on the board
QSE_Q: U8.2 (D), U8.9 (Q); also elsewhere on the board
RES: J2.3, U4.15 (RST), U5.27 (P1[2]_XRES)
SCK1: U4.6 (SCKI1), U5.2 (P12[3])
SCK2: U4.9 (SCKI2), U5.3 (P0[0])
SCL: R1.1, U2.8 (SCL), U4.1 (MC/SCL/FLT), U5.11 (P0[7])
SDA: R2.1, U2.7 (SDA), U4.2 (MD/DEMP/SDA), U5.10 (P0[6])
SWDCLK: J2.4, U5.26 (P1[1]_SWDCK)
SWDIO: J2.5, U5.25 (P1[0]_SWDIO)
USB+: R6.2, U5.34 (P15[6]_USB+)
USB-: R7.2, U5.35 (P15[7]_USB-)
USBV+: R4.1, R5.1, U5.33 (P1[7])
VCOM: C75.1, C76.1, U4.21 (VCOM); also elsewhere on the board
VINL: U4.25 (VINL); also elsewhere on the board
VINR: U4.26 (VINR); also elsewhere on the board
VOUTL+: U4.20 (VOUTL+); also elsewhere on the board
VOUTL-: U4.19 (VOUTL-); also elsewhere on the board
VOUTR+: U4.18 (VOUTR+); also elsewhere on the board
VOUTR-: U4.17 (VOUTR-); also elsewhere on the board
Vccd: C4.1, U5.12 (Vccd), U5.38 (Vccd)
XTALi: C10.1, U5.40 (P15[1]_XTALi), Y1.1
XTALo: C12.1, U5.39 (P15[0]_XTALo), Y1.3

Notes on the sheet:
BOOT jumper 1-2 enables USB bootloader. 2-3 for normal operation

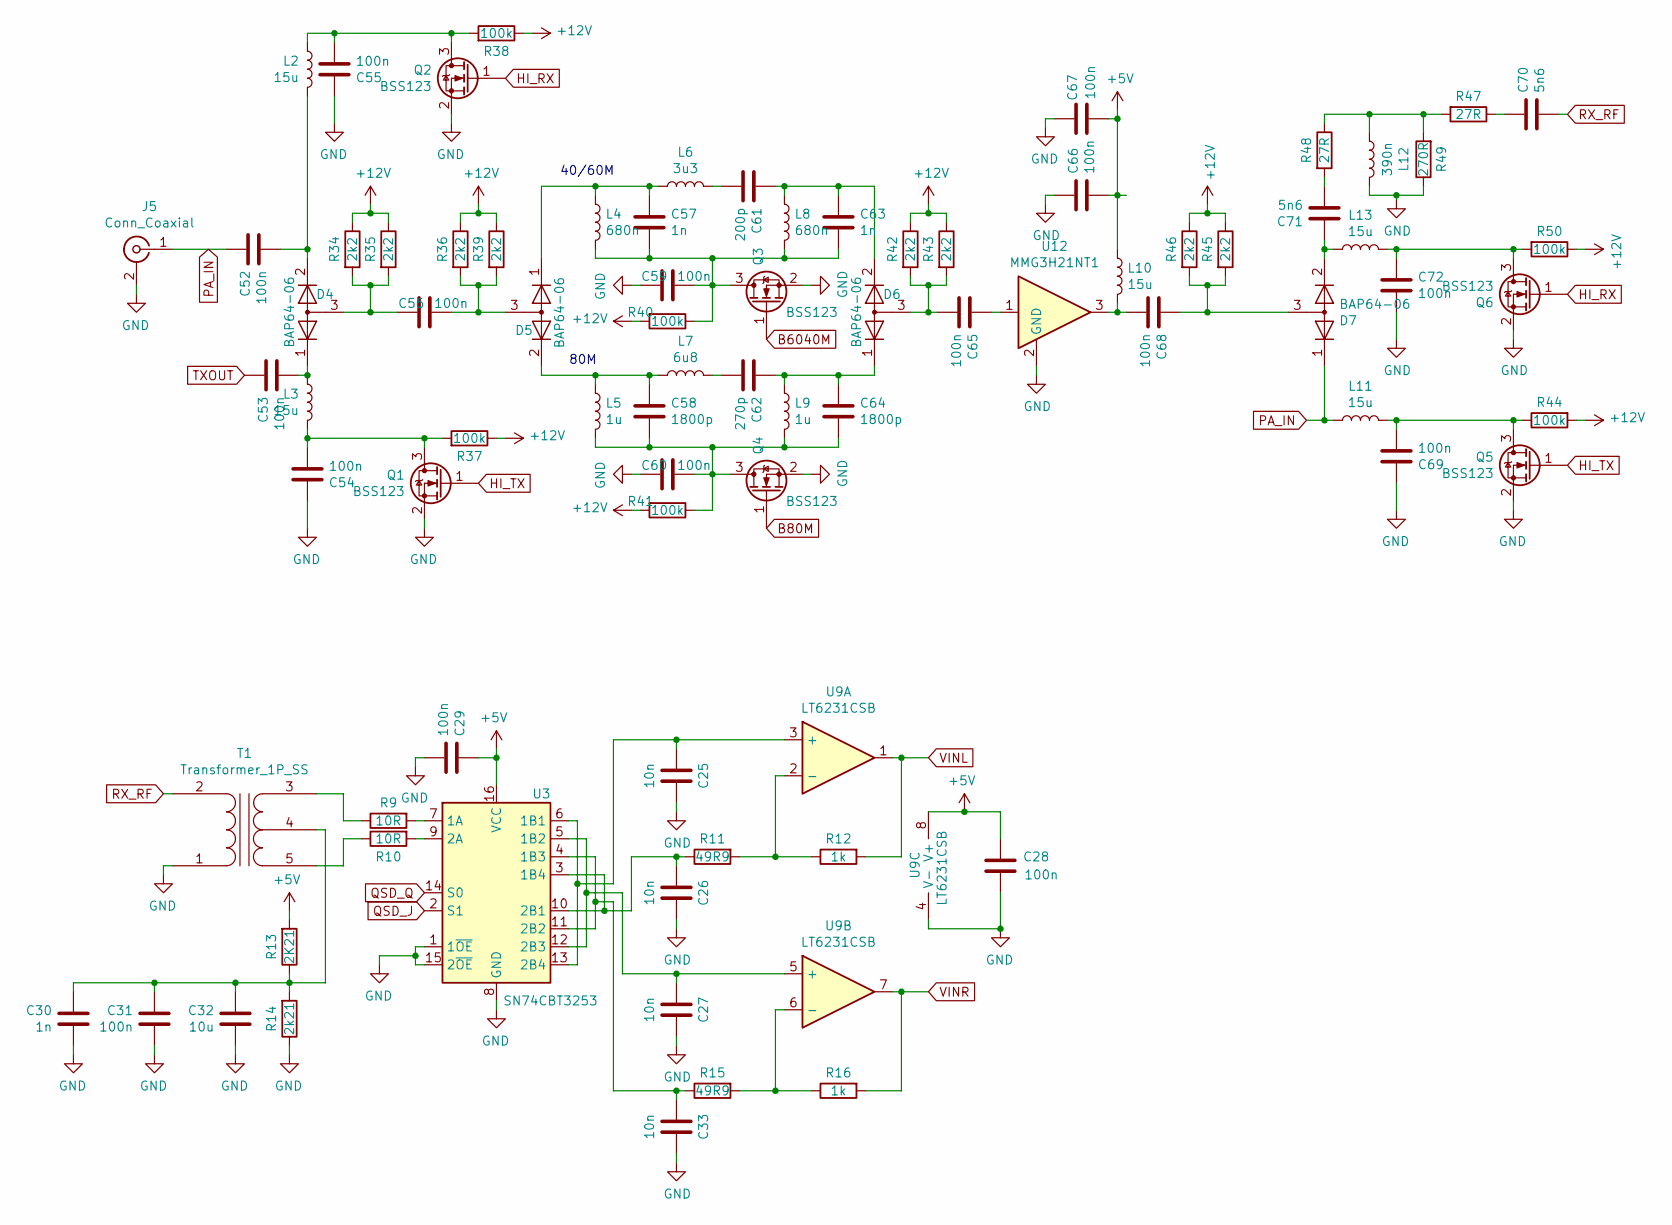
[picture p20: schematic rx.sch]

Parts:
C25, C26, C27, C33: 10n; C_0603_1608Metric
C28, C29, C31, C52, C53, C54, C55, C56, C59, C60, C65, C66, C67, C68, C69, C72: 100n; C_0603_1608Metric
C30, C57, C63: 1n; C_0603_1608Metric
C32: 10u; C_0805_2012Metric
C58, C64: 1800p; C_0603_1608Metric
C61: 200p; C_0603_1608Metric
C62: 270p; C_0603_1608Metric
C70, C71: 5n6; C_0603_1608Metric
D4, D5, D6, D7: BAP64-06; SOT-23
J5: Conn_Coaxial; SMA_Amphenol_132289_EdgeMount
L2, L3, L10, L11, L13: 15u; L_Taiyo-Yuden_NR-30xx_HandSoldering
L4, L8: 680n; L_Abracon_ASPI-3012S
L5, L9: 1u; L_Abracon_ASPI-3012S
L6: 3u3; L_Abracon_ASPI-3012S
L7: 6u8; L_Abracon_ASPI-3012S
L12: 390n; L_0805_2012Metric
Q1, Q2, Q3, Q4, Q5, Q6: BSS123; SOT-23
R9, R10: 10R; R_0603_1608Metric
R11, R15: 49R9; R_0603_1608Metric
R12, R16: 1k; R_0603_1608Metric
R13: 2K21; R_0603_1608Metric
R14: 2k21; R_0603_1608Metric
R34, R35, R36, R39, R42, R43, R45, R46: 2k2; R_0603_1608Metric
R37, R38, R40, R41, R44, R50: 100k; R_0603_1608Metric
R47, R48: 27R; R_0603_1608Metric
R49: 270R; R_0603_1608Metric
T1: Transformer_1P_SS; Transformer_MACOM_SM-22
U3: SN74CBT3253; SOIC-16_3.9x9.9mm_P1.27mm
U9: LT6231CSB; SOIC-8_3.9x4.9mm_P1.27mm
U12: MMG3H21NT1; SOT-89-3

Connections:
+5V: C28.1, C29.1, C66.2, C67.2, L10.1, R13.2, U3.16 (VCC), U9.8 (V+); also elsewhere on the board
+12V: R34.1, R35.1, R36.1, R37.1, R38.1, R39.1, R40.2, R41.2, R42.1, R43.1, R44.2, R45.1, R46.1, R50.1; also elsewhere on the board
B80M: Q4.1 (G); also elsewhere on the board
B6040M: Q3.1 (G); also elsewhere on the board
GND: C25.1, C26.1, C27.1, C28.2, C29.2, C30.2, C31.2, C32.2, C33.1, C54.1, C55.1, C59.2, C60.2, C66.1, C67.1, C69.1, C72.2, J5.2 (Ext), L12.2, Q1.2 (S), Q2.2 (S), Q3.2 (S), Q4.2 (S), Q5.2 (S), Q6.2 (S), R14.1, R49.1, T1.1 (AA), U3.1 (1~OE), U3.8 (GND), U3.15 (2~OE), U9.4 (V-), U12.2 (GND); also elsewhere on the board
HI_RX: Q2.1 (G), Q6.1 (G); also elsewhere on the board
HI_TX: Q1.1 (G), Q5.1 (G); also elsewhere on the board
unnamed: C25.2, U3.6 (1B1), U3.13 (2B4), U9.3 (+)
unnamed: C26.2, R11.1, U3.3 (1B4), U3.10 (2B1)
unnamed: C27.2, U3.5 (1B2), U3.12 (2B3), U9.5 (+)
unnamed: C30.1, C31.1, C32.1, R13.1, R14.2, T1.4 (SC)
unnamed: C33.2, R15.1, U3.4 (1B3), U3.11 (2B2)
unnamed: C52.2, D4.2 (K), L2.1
unnamed: C53.2, D4.1 (K), L3.2
unnamed: C54.2, L3.1, Q1.3 (D), R37.2
unnamed: C55.2, L2.2, Q2.3 (D), R38.2
unnamed: C56.1, D5.3 (A), R36.2, R39.2
unnamed: C56.2, D4.3 (A), R34.2, R35.2
unnamed: C57.1, D5.1 (K), L4.1, L6.1
unnamed: C57.2, C59.1, C63.2, L4.2, L8.2, Q3.3 (D), R40.1
unnamed: C58.1, D5.2 (K), L5.1, L7.1
unnamed: C58.2, C60.1, C64.2, L5.2, L9.2, Q4.3 (D), R41.1
unnamed: C61.1, C63.1, D6.2 (K), L8.1
unnamed: C61.2, L6.2
unnamed: C62.1, C64.1, D6.1 (K), L9.1
unnamed: C62.2, L7.2
unnamed: C65.1, U12.1
unnamed: C65.2, D6.3 (A), R42.2, R43.2
unnamed: C68.1, D7.3 (A), R45.2, R46.2
unnamed: C68.2, L10.2, U12.3
unnamed: C69.2, L11.1, Q5.3 (D), R44.1
unnamed: C70.1, R47.1
unnamed: C71.1, D7.2 (K), L13.1
unnamed: C71.2, R48.2
unnamed: C72.1, L13.2, Q6.3 (D), R50.2
unnamed: L12.1, R47.2, R48.1, R49.2
unnamed: R9.1, T1.3 (SA)
unnamed: R9.2, U3.7 (1A)
unnamed: R10.1, T1.5 (SB)
unnamed: R10.2, U3.9 (2A)
unnamed: R11.2, R12.1, U9.2 (-)
unnamed: R15.2, R16.1, U9.6 (-)
PA_IN: C52.1, D7.1 (K), J5.1 (In), L11.2
QSD_J: U3.2 (S1); also elsewhere on the board
QSD_Q: U3.14 (S0); also elsewhere on the board
RX_RF: C70.2, T1.2 (AB)
TXOUT: C53.1; also elsewhere on the board
VINL: R12.2, U9.1; also elsewhere on the board
VINR: R16.2, U9.7; also elsewhere on the board

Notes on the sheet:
80M
40/60M

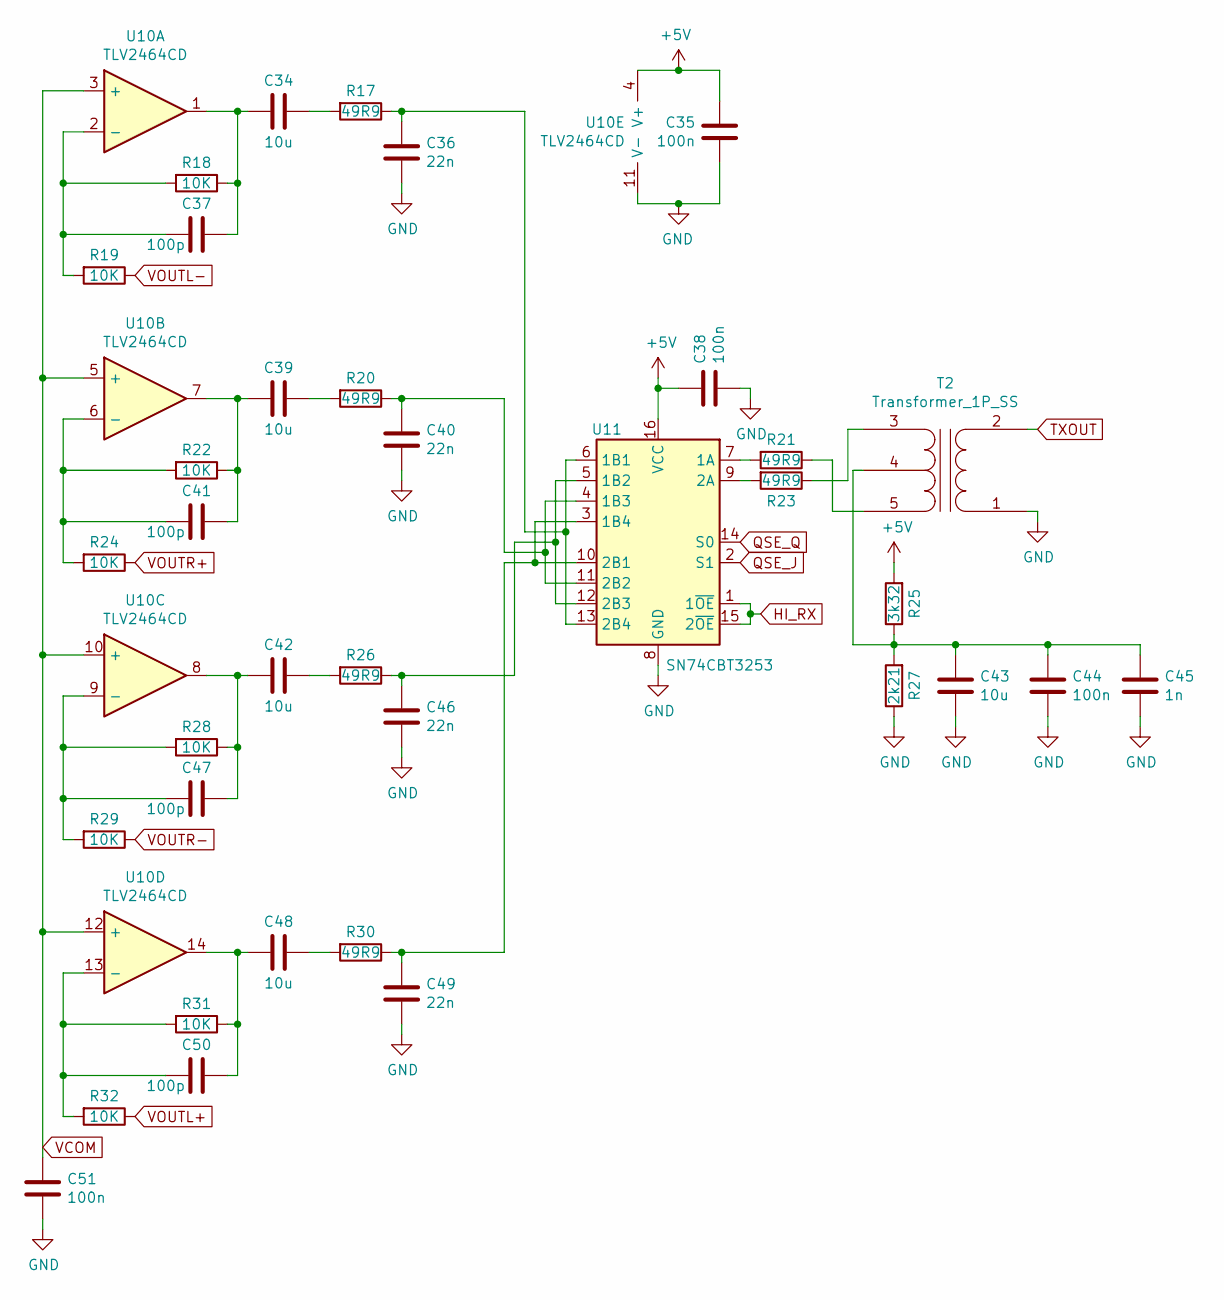
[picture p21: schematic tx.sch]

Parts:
C34, C39, C42, C43, C48: 10u; C_0805_2012Metric
C35, C38, C44, C51: 100n; C_0603_1608Metric
C36, C40, C46, C49: 22n; C_0603_1608Metric
C37, C41, C47, C50: 100p; C_0603_1608Metric
C45: 1n; C_0603_1608Metric
R17, R20, R21, R23, R26, R30: 49R9; R_0603_1608Metric
R18, R19, R22, R24, R28, R29, R31, R32: 10K; R_0603_1608Metric
R25: 3k32; R_0603_1608Metric
R27: 2k21; R_0603_1608Metric
T2: Transformer_1P_SS; Transformer_MACOM_SM-22
U10: TLV2464CD; SOIC-14_3.9x8.7mm_P1.27mm
U11: SN74CBT3253; SOIC-16_3.9x9.9mm_P1.27mm

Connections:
+5V: C35.1, C38.1, R25.2, U10.4 (V+), U11.16 (VCC); also elsewhere on the board
GND: C35.2, C36.2, C38.2, C40.2, C43.2, C44.2, C45.2, C46.2, C49.2, C51.2, R27.1, T2.1 (AA), U10.11 (V-), U11.8 (GND); also elsewhere on the board
HI_RX: U11.1 (1~OE), U11.15 (2~OE); also elsewhere on the board
unnamed: C34.1, R17.2
unnamed: C34.2, C37.1, R18.1, U10.1
unnamed: C36.1, R17.1, U11.6 (1B1), U11.13 (2B4)
unnamed: C37.2, R18.2, R19.2, U10.2 (-)
unnamed: C39.1, R20.2
unnamed: C39.2, C41.1, R22.1, U10.7
unnamed: C40.1, R20.1, U11.4 (1B3), U11.11 (2B2)
unnamed: C41.2, R22.2, R24.2, U10.6 (-)
unnamed: C42.1, R26.2
unnamed: C42.2, C47.1, R28.1, U10.8
unnamed: C43.1, C44.1, C45.1, R25.1, R27.2, T2.4 (SC)
unnamed: C46.1, R26.1, U11.5 (1B2), U11.12 (2B3)
unnamed: C47.2, R28.2, R29.2, U10.9 (-)
unnamed: C48.1, R30.2
unnamed: C48.2, C50.1, R31.1, U10.14
unnamed: C49.1, R30.1, U11.3 (1B4), U11.10 (2B1)
unnamed: C50.2, R31.2, R32.2, U10.13 (-)
unnamed: R21.1, T2.5 (SB)
unnamed: R21.2, U11.7 (1A)
unnamed: R23.1, T2.3 (SA)
unnamed: R23.2, U11.9 (2A)
QSE_J: U11.2 (S1); also elsewhere on the board
QSE_Q: U11.14 (S0); also elsewhere on the board
TXOUT: T2.2 (AB); also elsewhere on the board
VCOM: C51.1, U10.3 (+), U10.5 (+), U10.10 (+), U10.12 (+); also elsewhere on the board
VOUTL+: R32.1; also elsewhere on the board
VOUTL-: R19.1; also elsewhere on the board
VOUTR+: R24.1; also elsewhere on the board
VOUTR-: R29.1; also elsewhere on the board

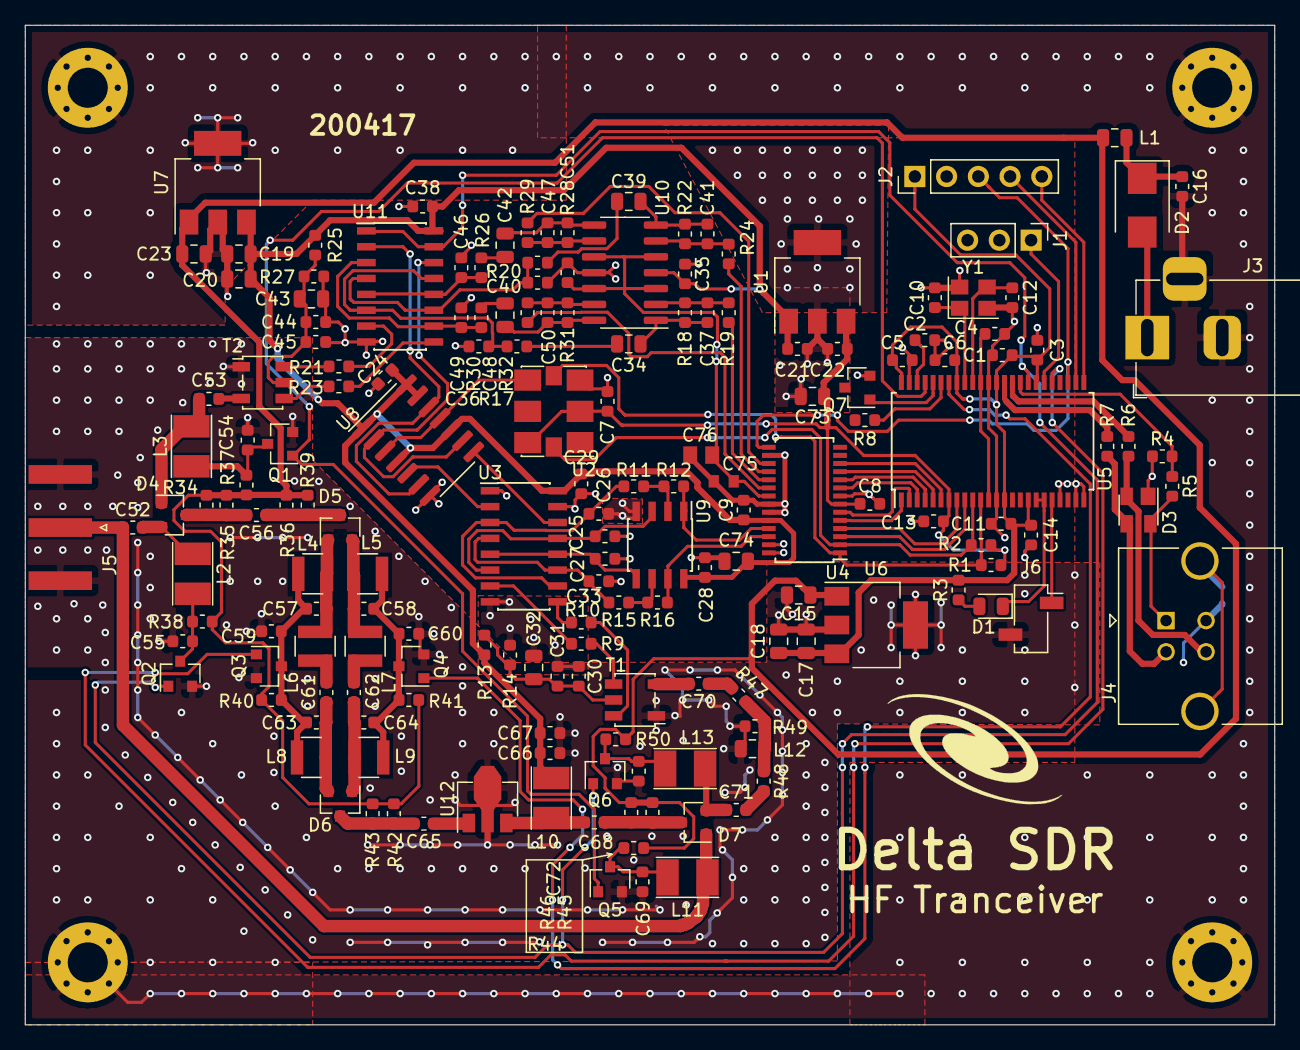
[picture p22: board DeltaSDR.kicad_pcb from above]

Board: 2 copper layers, 100.0 x 80.0 mm, 178 parts (1 on the bottom side), 112 nets.

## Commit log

2020-04-07 Schemtic: MCU, Codec, Basic RX and TX
    [DeltaSDR.kicad_pcb, DeltaSDR.sch, rx.sch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]
2020-04-09 Added RF front end and LNA
    [DeltaSDR.sch, rx.sch, tx.sch]
2020-04-10 First layouting
    [DeltaSDR.sch, rx.sch, tx.sch]
2020-04-11 Layout: All components connected
    [DeltaSDR.kicad_pcb, rx.sch]
2020-04-11 Changed RF front end layout
    [DeltaSDR.kicad_pcb]
2020-04-12 Added remaining switching signals and polygons
    [DeltaSDR.kicad_pcb, DeltaSDR.sch, tx.sch]
2020-04-12 Changed board size, changed PA_IN signal position, changed LDOs, added 50 ohm tracks andvias
    [DeltaSDR.kicad_pcb, DeltaSDR.sch, rx.sch]
2020-04-13 Changed connectors position, ground separation, added lot of vias
    [DeltaSDR.kicad_pcb]
2020-04-13 Improved ground separation and silk screen
    [DeltaSDR.kicad_pcb]
2020-04-13 ERC, DRC done, added output for ATU and AMP
    [DeltaSDR.kicad_pcb, DeltaSDR.sch, rx.sch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]
2020-04-14 Changed LO position and OPAMPs wiring
    [DeltaSDR.kicad_pcb]
2020-04-16 PCM3060 suplied from different voltage rail. Improved ground separation and USB layout
    [DeltaSDR.kicad_pcb, DeltaSDR.sch]
2020-04-17 Release. Generated gerbers and BOM
    [DeltaSDR-B_Cu.gbr, DeltaSDR-B_Mask.gbr, DeltaSDR-B_Paste.gbr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]
2020-08-25 Corrected Q6 connection, RX schematic clean up
    [DeltaSDR.kicad_pcb, DeltaSDR.sch, rx.sch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]
2020-08-25 Changed mixers footprints, added 3D models, silk screen correction
    [DeltaSDR.kicad_pcb, rx.sch, tx.sch]
2020-08-25 Improved band pass filter layout
    [DeltaSDR.kicad_pcb]
2020-08-25 Changed layout of LT6231, changed RX transformer caps ground.
    [DeltaSDR.kicad_pcb, DeltaSDR.sch, rx.sch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]
2020-08-26 Improved layout of band pass switches, edited README.md
    [DeltaSDR.kicad_pcb]
2020-08-26 Added latest FW, Win USB driver and references
2020-08-28 Changed LDOs
    [DeltaSDR.kicad_pcb, DeltaSDR.sch, rx.sch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]
2020-08-31 Wrong TX resistors values correction.
    [DeltaSDR.kicad_pcb, tx.sch]
2020-09-11 Corrected wrong TX opamp capacitors values
    [DeltaSDR.kicad_pcb, tx.sch]
2020-09-11 TX opamp improved layout.
    [DeltaSDR.kicad_pcb]
2020-09-11 Added capacitors to codec's VCOM
    [DeltaSDR.kicad_pcb, rx.sch]
2020-09-16 Minor SilkScreen layer improvement
    [DeltaSDR.kicad_pcb]
2020-09-19 A lot of minor layout changes
    [DeltaSDR.kicad_pcb, DeltaSDR.sch, pokus.kicad_pcb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]
2020-09-21 TX sample caps closer to MUX, changed SI570 orientation
    [DeltaSDR.kicad_pcb]
2020-09-22 Added TX spectrum measurement
    [DeltaSDR.kicad_pcb]
